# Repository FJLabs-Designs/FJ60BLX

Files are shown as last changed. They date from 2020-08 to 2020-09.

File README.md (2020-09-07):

# FJ60BLX Bluetooth 60% Mechanical Keyboard PCB

The following repository will hold the design files of the FJ60BLX Bluetooth Mechanical Keyboard PCB. This is designed to be a living repository and design files in this repository will be continually updated as the board iterates and changes.

## About this Repository

This repository contains rolling updates to the FJ60BLX Bluetooth PCB. Included are the base Eagle files (Board File, Schematic, and CAM Processor Job), the associated Gerber files for that revision, and the associated Bills of Materials. Each of these files will be segregated into their respective versions that are date-coded with the day of export. 

## Eagle Files

The core of this repository are the bare Eagle files. These files are the basis for the Gerber exports. **When using the eagle files, please remove the FJLabs and FJ60BLX branding.**

## Gerber Files

Included are the Gerber Files for manufacturing. These should be available in 5.6 format for all copper layers, and 4.5 format for all drills. Your PCB manufacturer requires these files to create the PCB itself. Additionally, included in the Gerber files are the relevant Pick and Place Coordinate/Centroid files which are needed for PCBA. 

## BOM Files

The included BOM files are available as Excel spreadsheets with LCSC links whereever possible. Certain components are not available from LCSC and must be purchased either directly from the manufacturer or from an authorized components distributor. 

## Renders

This folder includes a master list of all renders that have been sent to subscribers of the FJ60BLX mailing list and are date-coded. 

## Manufacturing Information

### Bluetooth Module

The PCB uses the MDBT40-256v3 Bluetooth module designed and manufactured by Raytac. This module must be programmed with the Adafruit Bluefruit SPI Friend firmware for compatibility with QMK. The relevant firmware has not been included as it is property of Adafruit and its respective company. However, this firmware is available for free open-source on GitHub (link not provided). Additionally, a SoftDevice file is required for programming of the bare Bluetooth module, which is included in the Adafruit repository for the Nordic 51822 chipset. 

Instructions are not included for programming the Bluetooth module over SWD, as it is more productive to purchase such modules pre-programmed directly from the manufacturer. The difference in cost between a programmed and unprogrammed module is negligble and therefore, for production, it is *highly recommended* to purchase preflashed chips.

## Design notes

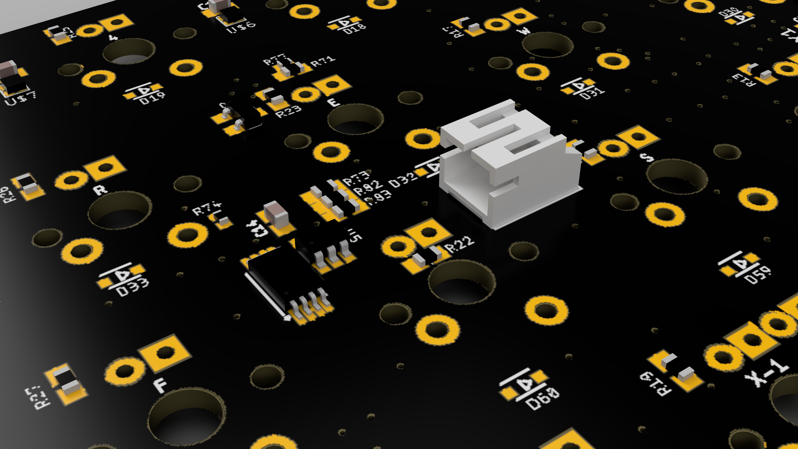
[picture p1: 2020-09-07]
Renders/v1-8-11-20-battery.png

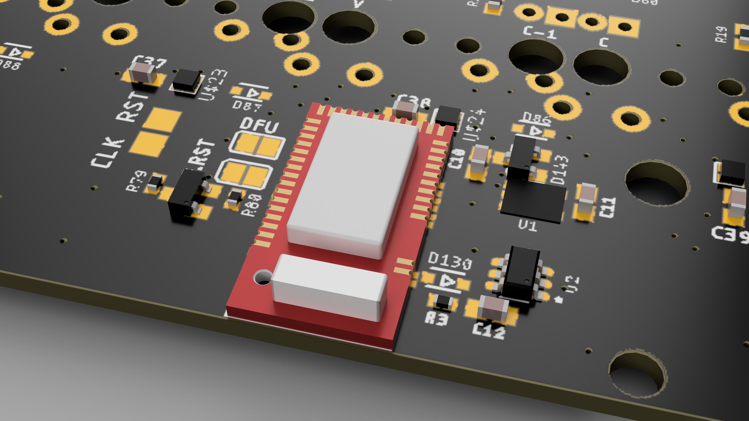
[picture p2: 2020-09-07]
Renders/v1-8-11-20-bluetooth.png

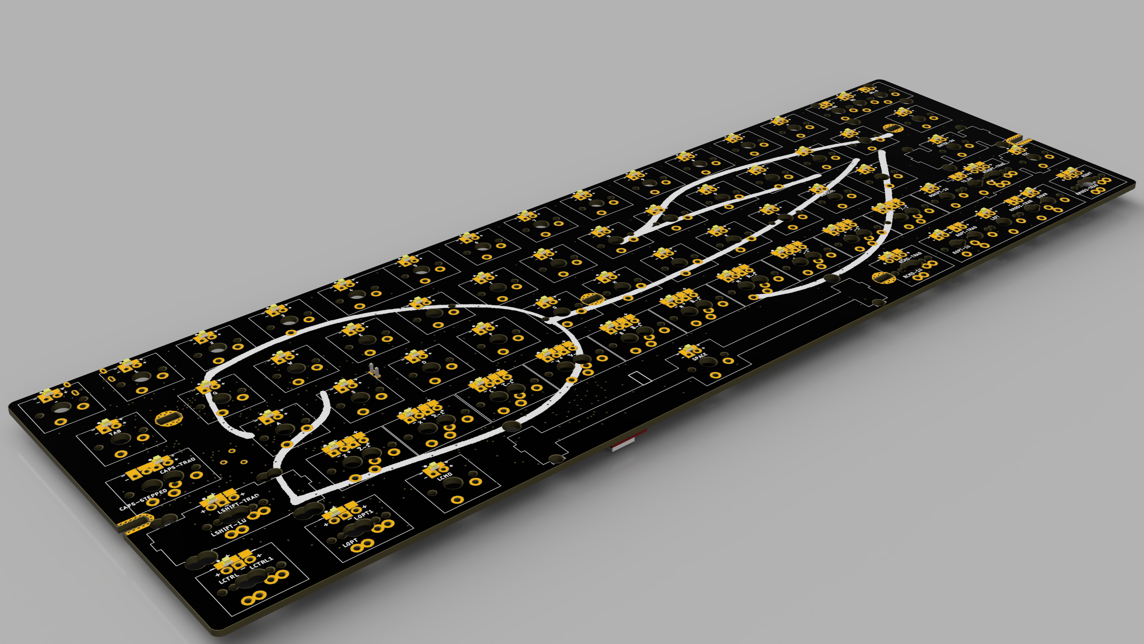
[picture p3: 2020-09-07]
Renders/v1-8-20-20-topart2.png

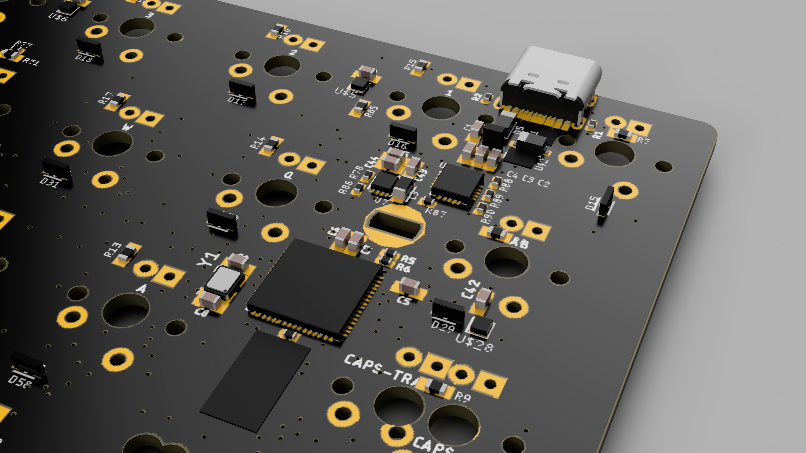
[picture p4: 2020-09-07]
Renders/v1-8-11-20-power.png

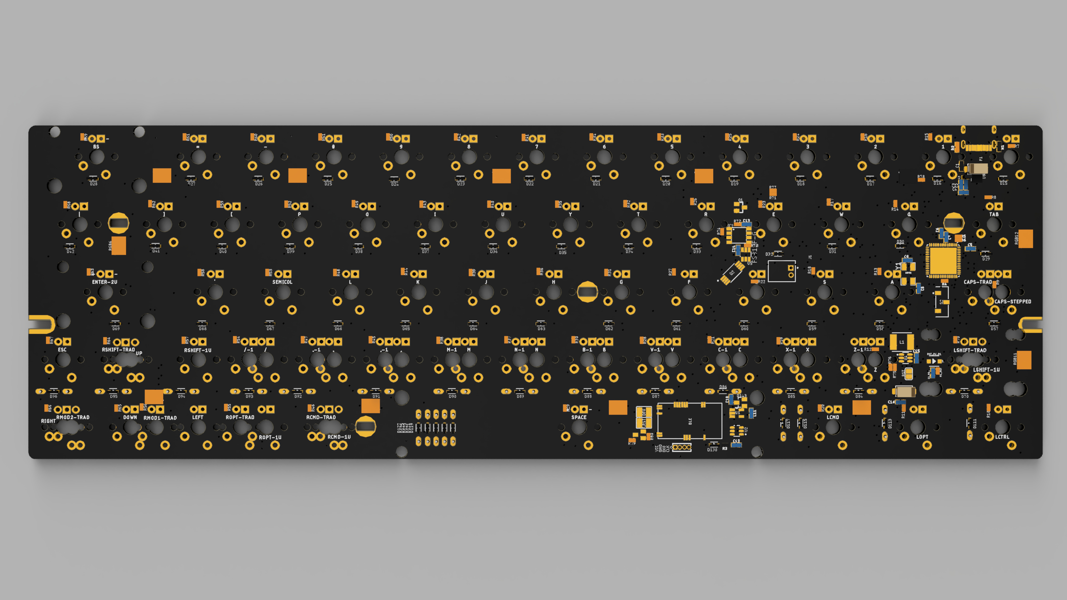
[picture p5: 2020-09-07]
Renders/v1-7-19-20-Bottom.jpg

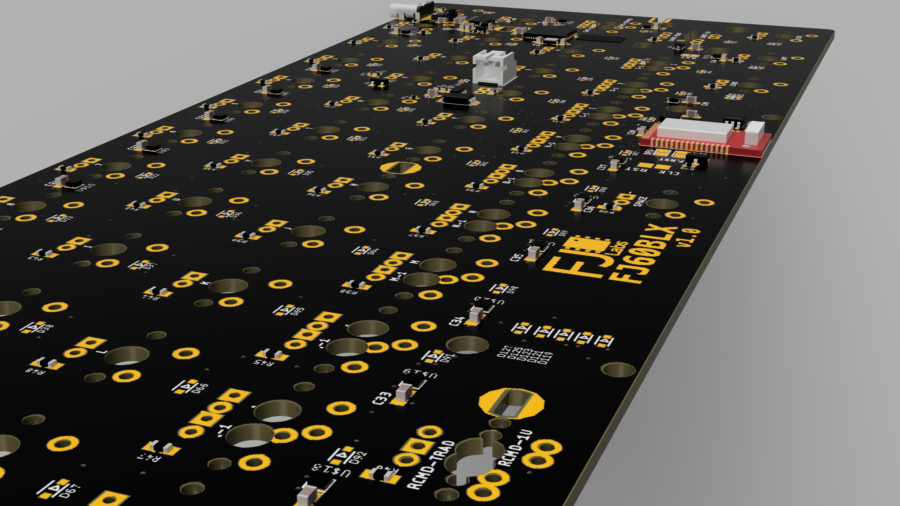
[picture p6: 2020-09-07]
Renders/v1-8-11-20-whole.png

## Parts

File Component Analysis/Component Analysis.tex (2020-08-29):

\documentclass[11pt]{article}

\usepackage[utf8]{inputenc}
\usepackage[T1]{fontenc}
\usepackage{amsmath}
\usepackage{indentfirst}
\usepackage[letterpaper]{geometry}
\usepackage{hyperref}
\usepackage{graphicx}
\usepackage{wrapfig}
\usepackage[bottom]{footmisc}
\usepackage{siunitx}
\usepackage{circuitikz}
\usepackage{array}
\usepackage{tikz}

\pagestyle{headings}

\begin{document}

\author{FJ Labs\footnotemark}
\title{FJ60BLX Component Choice and Analysis}
\date{August 21, 2020}
\maketitle

\tableofcontents

\newpage

\footnotetext{I would like to give special thanks to Hadi Iskandarani, his associated Discord group and Youtube channel, without whom this PCB design would have more errors than accuracies. As well, I would like to thank those kind enough to provide advice and support during the design stages of the board, answering my numerous questions without fail.}

\section{Introduction}

This document is intended to be a live document with a full description of the rationale for the primary component choices, the impetus behind why design choices were made, and an analysis of the availability and producibility of the components.

Major sections are divided into the core subsystems of the board starting from the core keyboard functionality then progressing to the additional functions added.

\section{Keyboard Overview}

The vision for the FJ60BLX PCB was to create an "all-in-one" PCB for the universal 60\% keyboards, including the KBDFans Tofu and 5Degrees cases, as well as similar generic cases. The primary feature draw of the keyboard is the Bluetooth functionality and full QMK support. Additional \emph{quality of life} features include under-glow RGB support and per-key backlighting. 

As such, the overarching theme of the design process has been to support Bluetooth in \emph{any way possible}. Much of the rationale behind each of the subsections follows from this core idea, and the remainder of the document should be read with it in mind.

\section{Microcontroller}

\subsection{Microcontroller Choice}

The main microcontroller for this board is the AT90USB646-MU. First and foremost, I address why this microcontroller was chosen over a smaller, cheaper, and more simple, Atmega32u4. For those knowledgable in keyboard PCB's, you will know the Atmega chip to be the bread and butter of keyboards. Unfortunately, this chip was simply not suitable for the FJ60BLX.

Let's first look at why the Atmega32U4 is so popular. First of all, it is a cheap, widely-produced microcontroller, which can easily be purchased under \$2 when produced at scale. Furthermore, it has most of the features necessary for operation under QMK, including 32KB of onboard flash memory and total of 26 I/O [input-output, GPIO] lines available. As well, it is a rather low-power device, consuming around $\SI{15}{\milli\ampere}$ at load when run with the usual specifications. It operates on a wide voltage range, functional from 2.7V to 5.5V. All these features make the chip ideal for a low-complexity device like a mechanical keyboard, whose sole purpose is to provide input and output.

\subsection{Why not the Atmega32U4?}

With that out of the way, let's talk about why I am \emph{not} using the Atmega32U4 for this keyboard, even though it seems like the perfect candidate.

The FJ60BLX consists of a matrix with rows and columns \([5,14]\). To maintain a proper matrix, as well as avoid ghosting of the keys, this, at minimum required 19 microcontroller pins. I am aware that alternative matrix combinations could have been arranged to reduce the number of pins needed (\emph{i.e.}, \([8,9]\)). However, this would not correspond logically to the actual layout of the keyboard, causing headaches when actually laying out the matrix, and even doing the keymaps in software. Thus, we are left with requiring 19 pins for the matrix.

For most boards, the Atmega32U4 can easily handle the 19 matrix pins without an issue (and that's why most boards use it). However, the FJ60BLX requires multiple additional pins, specifically for the Bluetooth support, under-glow, and backlight support. 

The Bluetooth module requires a minimum of 5 total pins (\emph{See supra., Bluetooth}). Additionally, RGB under-glow using addressable RGB LED's requires 1 pin (\emph{See supra, Under-glow}). Per-Key LED lightning using a common-cathode setup requires 1 pin (\emph{See supra, Per-Key LED)}. With this, our total pin count was brought up to 26 pins, the total available for the Atmega32U4 in terms of GPIO. Additionally, there are a few pins which are reserved for other purposes in the Atmega32U4 (\emph{i.e.}, Pin E2 (HWB)).

\subsection{Why the AT90USB646?}

As described above, the Atmega32U4 was likely not a suitable chip for this keyboard given the number of additional pins needed. Therefore, the search was on for an alternative chip. 

One of the primary drivers for the chip choice was QMK support. QMK, while being a great piece of software, has limited chip support\footnotemark \footnotetext{ \emph{See} QMK list of compatible microcontrollers at  \url{https://docs.qmk.fm/\#/compatible\_microcontrollers} }  due to its open-source nature. QMK supports two main types of microprocessors architectures, ARM and AVR. Immediately, ARM chips were ruled out, as I am not knowledgable about ARM, and do not wish to set too far out of my software comfort-zone, for a hardware project. 

Among the supported QMK AVR chips are the Atmega32U4 family, AT90USB646 family, and the Atmega32u2 family. Other AVR chips are also supported, but they do not use the LUFA USB stack, so they forgo native USB-support. Having ruled out the Atmega32U4, the Atmega32U2 family was also excluded due to even more reduced feature sets. Thus, we are left with the AT90USB646 family of chips.

The AT90USB646 family is class of chips which include the AT90USB646/647 and the AT90USB1286/1287. We'll first rule out the AT90USB1286/1287 lines. These chips contain 128KB of available flash memory (hence the product name). As QMK fits comfortable in even 32KB of flash\footnotemark \footnotetext{The Atmega32U[x] series has 32KB of flash and support QMK. Additionally, according to QMK documentation, 16KB flash chips are supportable, if features are selectively disabled from the firmware}, 128KB of flash was simply too much. We are then left with the AT90USB646/647 class.

The AT90USB646 and AT90USB647 are delineated by their USB interface version. The 646-type chips present the USB interface as a \emph{device} whereas the 647-type chips present the USB interface as a \emph{USB OTG} standard. Without diving much into the complexities of USB negotiation, the correct choice for a keyboard would be \emph{device} mode—the 646-type chips. Therefore, the final chip model was nailed down to the AT90USB646.

Of course, let's sanity check the chip to make sure it can do what we need. First of all, this chip has a total of 48 I/O lines, a much higher number compared to the 26 of the Atmega. Therefore, this chip can easily handle all the features we will throw at it. Additionally, this chip supports all the extra hardware features the Atmega32U4 does without sacrificing much. Power consumption is marginally higher, but this will be addressed in a later section.\footnotemark \footnotetext{\emph{See supra. Power Management}.}

\subsection{Package Choice}

The AT90USB646 is offered in 2 versions—a QFP and QFN package. To most, these package names seem completely foreign, but actually matter quite heavily during designing. The chips in each package are identical, but each package takes up a different amount of room of the circuit board when placed down. Therefore, care must be chosen when choosing a proper package for a chip, given constraints on board side and available room.

QFP [Quad Flat Pack] packages are very common and present themselves with exposed leads for each of the pins of the IC. \emph{See Figure 1} QFN [Quad Flat No-Leads] packages are much smaller packages, which do not have leads, but instead, have the connection points on the underside of the chip itself. \emph{See Figure 2}. 

\begin{wrapfigure}{r}{0.5\linewidth}
	\centering
	
	\caption{Atmega32U4 in QFP.}
\end{wrapfigure}

\vspace{1.5cm}

\begin{wrapfigure}{r}{0.5\linewidth}
	\centering
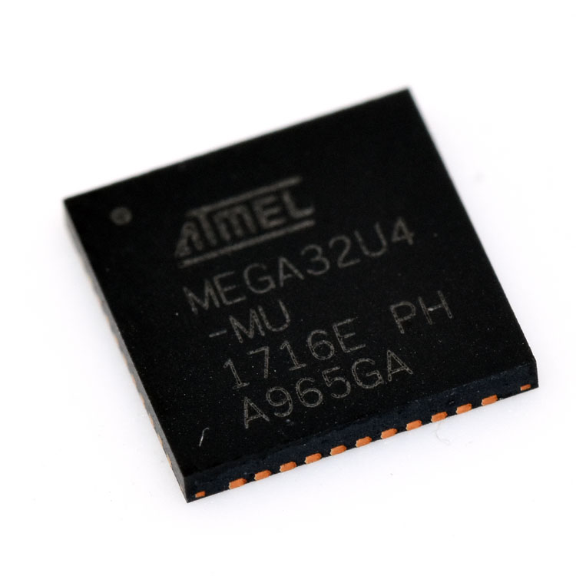
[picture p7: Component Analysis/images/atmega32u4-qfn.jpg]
	
	\caption{Atmega32U4 in QFN.}
\end{wrapfigure}	

One of the primary constraints in package choice was that I wanted the microcontroller to sit squarely in between the Tab and Q keys. Partly, this was simply for a challenge. As well, I wished to avoid having to bring the USB data lines down below to somewhere with more space like around the spacebar. As the amount of space between those two keys is actually quite small, the natural choice was to go with the QFN package.

The QFN, given its size, is not without its drawbacks. Most notably, this chip is not hand-solderable in any sense of the imagination.\footnotemark \footnotetext{I am aware that drag-soldering is possible with a QFN package. However, without enough practice and also a very skilled hand, this is an incredibly difficult task. Even most professionals would regard this task as foolish.} Another drawback is the lack of ability to detect errors in manufacturing with this package type, as the solder pads are primarily below the chip itself. These problems will hopefully be remedied through functional testing by the PCB manufacturer themselves at additional cost.

\subsection{Component Availability}

This microcontroller is a widely used part and is not expected to face any component shortages. These can be purchased from most online component distributors as well as directly from the manufacturer. As such, no production challenges are expected from this chip choice.

\section{Bluetooth}

The Bluetooth chip of choice in this build is the Raytac MDBT40-256v3,\footnotemark \footnotetext{\url{https://www.raytac.com/product/ins.php?index\_id=63}} based off the Nordic nRF51822 ARM Cortex M0. To be brief, the reason this chip was chosen was off-the-shelf QMK support\footnotemark \footnotetext{I am not a C programmer, and I do not want to redevelop a Bluetooth implementation purely from scratch.} and reasonable cost. 

\subsection{Origins of this chip}

For those versed in QMK's documentation, you will know that QMK lists a few chips as \emph{supported} with the recommended being the Adafruit Bluefruit SPI Friend.\footnotemark \footnotetext{\url{www.adafruit.com/product/2633}}. Adafruit sells this module as a "breakout board" which is a pre-built carrier module for the chip as well as any supporting components. This sounds great! However, it is over \$15. Not great.

Instead, as the breakout board is simply a carrier board, I could easily rebuild the breakout board itself on the actual PCB, adding all the supporting components and main chip myself. \emph{I would like to give a huge shoutout to Adafruit for making not only their breakout boards available to the general public, but also their associated schematics.}\footnotemark \footnotetext{\url{https://cdn-learn.adafruit.com/assets/assets/000/026/205/original/adafruit\_products\_BluefruitLESPIFriend\_sch.png?1436186237}.}. Avoiding Adafruit's breakout board brings this chip down to around \$5 at scale per-chip and a few extra dollars for the surrounding supporting components. 

\subsection{Why this specific chip?}

The chip that Adafruit used for their breakout board is the MDBT40-256v3. Alternative versions of this chip are available as well, such as the MDBT40-P256v3 and MDBT40-256RV3. Differences between models are broken down in this section.

The difference between P and non-P models is the use of a chip antenna (non-P) vs a PCB antenna (P). Notably, chip antennas have greater signal strength and increased signal-to-noise ratio compared to their PCB antenna counterparts. In my original PCB vision, most boards would go into aluminum cases such as the Tofu, which tends to obstruct radio signals from passing through.\footnotemark \footnotetext{This effect is due primarily to the Faraday effect, with the case essentially acting as a Faraday cage, blocking RF in and out. A similar issue is faced with wireless charging and metal cases.} Therefore, signal strength was of \emph{utmost} importance when choosing the Bluetooth chip. Thus, P models were removed from consideration, despite being a tiny bit cheaper.

The difference between R and non-R models is the presence of extra RAM in the R models. Non-R models present a total of 16KB of useable RAM. This was determined to be sufficient as the Adafruit breakout board uses the non-R version and the Bluetooth chips will be running the identical Adafruit firmware. Therefore, R models were removed from consideration. 

The final model of this module being produced by Raytac is the MDBT40-256v3.

\subsection{Supporting Components}

The Bluetooth module chosen needs a few major supporting components to function properly in the FJ60BLX's circuit. These include a 5V-to-3.3V regulator and a level shifter. Most of the component choice was identical to that on the Adafruit breakout board, both due to simplicity as well as reliability and component availability. No future detail is given on the associated supporting components here.

\subsection{Component Availability}

The MDBT40-256v3 will be purchased through a direct purchasing relationship with the manufacturer. These chips are not readily available through component distributors due to rather niche nature. Instead, production supply has already been established and purchasing expectations have already been provided. Furthermore, purchasing directly from the manufacturer enables them to preprogram the chip with the requisite Adafruit firmware before assembly, saving time and error.

The supporting components are widely available from most component distributors. These are not in short supply and are quite generic in their nature. They may be swapped to equivalent components as many drop-in replacements exist. As such, they are not expected to be impediments to production.

\section{Power Management}

One of the most unique elements of the FJ60BLX is the inclusion of a multi-phasic power management scheme, built around Dynamic Power Path Management.\footnotemark \footnotetext{Dynamic Power Path Management (DPPM) is a T.I. specific branding of "Power Path Management."} As such, as a litany of additional components were added to support this, detailed in this section.

\subsection{Why DPPM?}

Most keyboards do not include a DPPM solution, so why did this keyboard need it? This was due to two competing electrical "dragons" in this board: 1) power savings due to being battery powered, and 2) high power draw due to the amount of LEDs. Most boards on the market are only faced with one of these dragons they need to contend with, instead of two completely mutually-exclusive ones.\footnotemark \footnotetext{Most boards with the amount of LED's present are only available in wired modes whereas most Bluetooth boards do not have so many LED's. Even notable boards like the Anne Pro 2 have fewer LED's than this board will have fully populated.} 

These two dragons have the following effects. A computer's standard USB port is typically limited to \(500mA\) of continuous current. Therefore, this acts as the upper ceiling of power draw from the board, to allow use when connected to USB and without a battery. The high amount of LED's will draw, at full load, a total of \(450mA\).\footnotemark \footnotetext{\emph{See supra, Under-glow} and \emph{Per-Key LEDs}} Therefore, to avoid LED's unfortunately being dimmed while simultaneously charging the battery, battery charging must be limited to \(50mA\) when LEDs are at full load. A typical 1800mAh battery, however will take:

$$ \frac{1800mAh}{50mA} = 36h $$

to achieve a full charge. This number is ridiculous and completely unacceptable for day-to-day use. Alternatively, power may have been divided equally between the battery charging and LEDs, leaving a \(250mA\) for both. This would give a battery charge time of:

$$ \frac{1800mAh}{250mA} = 7.2h $$

This is a much better result and somewhat more acceptable. What would be \emph{best} would be the ability to allow the LEDs to use as much power as they want, and redirect the entire remaining power budget of 500mA to the battery charger. Essentially, if a user turns off the LED's (\emph{e.g.,} before sleeping), the battery would be able to take advantage of almost all \(500mA\) power budget, giving a charge time of:

$$ \frac{1800mAh}{500mA} = 3.6h $$

This is a much greater result and is perfect for daily usage, with charging at night. This can only be accomplished with a Dynamic Power Path Management chip.

The primary ability of DPPM is to \emph{prioritize} system load from a total power budget, and redirect all remaining power for purposes of charging the battery. 

\subsection{Battery Charger}

Knowing that DPPM was required, the search for a battery charger chip was narrowed down.\footnotemark \footnotetext{The search for the chip was limited to Microchip chips as reliability was extremely important. Furthermore, Microchip provides immaculate documentation of their chips, providing detailed descriptions and implementation diagrams. I have also personally seen these chips in other products and Adafruit breakout boards, so I am aware of their basic implementation.} The Microchip MCP73871-2AAI/L was chosen as the final battery charger chip. 

This chip is a lithium-ion battery charger with integrated load-sharing power pathing (DPPM), with a total \(1.8A\) of input current, and \(1A\) charging. This was sufficient headroom over the maximum \(500mA\) power available through USB.\footnotemark \footnotetext{Alternative USB charging specifications are categorically not supported with this board. Any charger over 5V 500mA may have the potential to damage the board irreparably.} The feature set of this chip is extremely admirable, including all the needed features, plenty of headroom, and a large amount of programmable capability.

While such a powerful chip is, of course, not entirely necessary in the context of a DPPM charger circuit, their inclusion was certainly a plus. While many of the features were disabled or left unused, the system takes advantage of a handful. The charger offers built-in overheat protection, in the event that too much current gets drawn for the thermal capacity of the board. This will help prevent runaway charging fires common in poorly designed electronics. As well, the chip offers built-in automatic input-power switching, reducing overall component count and board space. Lastly, the amount of status LED's (while not on the final board design) will make circuit troubleshooting easy in the prototyping phases.

\subsubsection{Chip Models}

The MCP73871 is a family of chips that all offer the same basic functionality. Ultimately, the MCP73871-2AAI/L was chosen for its current availability (one of the only in the family that is available).

\subsubsection{Component Availability}

This chip appears to be widely available from most electronics components distributors as well as directly from the manufacturer. As such, no production challenges are expected from this chip choice.

\subsection{System Voltage and Power Conditions}

One of the biggest challenges with a battery powered system driving LEDs is power delivery. Lithium Ion batteries are known to produce a maximum voltage of \(4.2V\) and safe minimum voltage of \(3.0V\). In a very large amount of its battery life, the battery will operate at \(3.7V\). This is of slight concern as most RGB LEDs will operate at \(3.5V < V_f < 4.3V\). In other words, the LEDs may require up to \(4.3V\) to even turn on.

Clearly, running the entire system off a battery was not feasible. Therefore, voltage must be boosted to an acceptable level before being used by the system. 

It would be trivial to boost output voltage to \(5V\), but this presents drawbacks in terms of power efficiency. The AT90USB646 can draw as little as \(7.5mA\) at \(3.3V\) and a maximum of \(20mA\) at 5V. This presents a stark battery life contrast:

$$ \frac{1800mAh}{7.5mA} = 240h < \frac{1800mAh}{20mA} = 90h $$

This is a difference between running the keyboard for over a week and only 4 days. While the LED's can not run at 3.3V, a compromise can be made, at \(4.6V\). I chose not to skirt the minimum voltage of \(4.3V\) as diodes may present a forward voltage drop of typically \(200mV\): 

\begin{equation}
\begin{aligned}
V_{in} - V_{F} = V_{usable} \\
4.6V - 0.2V = 4.4V
\end{aligned}
\end{equation}

Additionally, as the Bluetooth module runs exclusively on 3.3V, the \(4.6V\) must be regulated down.\footnotemark \footnotetext{\emph{See infra. Bluetooth}} It's incredibly important to note that linear voltage regulators have a minimum voltage drop, defined as \(V_{Dropout} = V_{in} - V_{out}\). For the linear regulator chosen as part of the Bluetooth subsystem, the accompanying datasheet defined \(\max(V_{Dropout}) = 300mV\). Therefore, 

$$ \min(V_{In}) = V_{out} + \max(V_{Dropout}) = 3.3V + 0.3V = 3.6V $$

Clearly, this is in range of the \(V_{System} = 4.6V\) discussed earlier, so this subsystem is satisfied too. Furthermore, power loss (energy wasted as heat) on the system is fairly minimal given Bluetooth Low Energy's minimal power draw of around \(15mA\).

\begin{equation}
\begin{aligned}
P &= (V_{In} - V_{Out}) \times I \\
&= (4.6V - 3.3V) \times 0.015 \\
&= 0.0195W 
\end{aligned}
\end{equation}

Lately, of note is the interaction between battery power and USB power, in the presence of a DPPM. Previously mentioned, the DPPM chip will provide power to the system through the USB port when plugged in and via the battery otherwise. Thus, you are essentially left with two possible power conditions, \(3.0V \le V_{DPPM} \le 4.2V\) and \(V_{DPPM} = 5V \pm 0.25V\). 

So far, we have only looked at situations involving battery power. Reason being, the alternative power mode actually avoids most of the considerations previously mentioned. With \(V_{System} = 5V\), all LED's are easily driven. Furthermore, since the board is plugged in, battery life is not a concern. Lastly, the power loss of the Bluetooth chip is still quite minimal at \(0.0255W\). 

\subsection{Boost Converter}

Having decided on an appropriate system voltage, the final step was actually creating the voltage. It's important to note that battery voltage will always be lower than the system voltage, in other words, \(\forall V_{Batt}, V_{Batt} < V_{System}\). Therefore, in order to bring \(V_{Batt}\) to \(V_{System}\), we rely on a boost converter. The boost converter chosen was the TPS61252DSGT.

\subsubsection{Synchronous and Asynchronous Boost Converters}

There are two main types of boost converters available, synchronous and asynchronous. The basic method of operation of both is very similar, using energy stored in a magnetic field to provide additional voltage, with output voltage being controlled by a switching MOSFET that injects extra energy at the right time. The difference between the two boost "topologies" lies in the use of either a Schottky diode or a second MOSFET to control flyback current. 

As previously mentioned, all diodes have a forward voltage drop, \(V_F\). MOSFETs on the other hand behave similarly to "ideal diodes," theoretical one-way electric controls with a \(V_f \approx 0\). Asynchronous boost converters use a diode while a synchronous one uses a MOSFET. Recall how we also calculated power loss, which we can do similarly for an asynchronous converter, assuming an arbitrary \(V_{In}\) of a diode with a \(V_F = 300mV\), typical of Schottky diodes, and a current of \(500mA\).

\begin{equation}
\begin{aligned}
	P_{loss} &= (V_{In} - V_{Out}) \times I \\
	&= (V_{In} - (V_{In} - V_F) \times I \\
	&= V_F \times I \\
	&= 0.3V \times 0.5A \\
	P_{loss} &= 0.15W
\end{aligned}	
\end{equation}

While this may not seem like much, bear in mind that system at \(5V\) and \(500mA\) only consumes a power of \(2.5W\). This presents a 6\% power loss, a very inefficient design. A synchronous boost converter would have a power loss instead approaching zero, which is ideal. 

Therefore, in order to improve efficiency (and extend battery life), boost converter choices were limited to synchronous boost converters.

\subsubsection{Inductors and Switching Frequency}

As just mentioned, boost converters operate by storing energy in a magnetic field and later releasing this energy back into the circuit.\footnotemark \footnotetext{This arises out of Faraday's law of induction and Lenz's law.} The magnetic field is generated typically by an inductor. These are frequently seen as large windings of copper wire around a center core. While storing energy in the coil is great, if it is only stored and released once, that's not a useful change in voltage—that is merely a voltage spike, not at all helpful at driving components.

Instead, boost converters operate by storing and releasing energy from the magnetic field many hundreds of thousands of times a second. This gives boost converters the name "switch-mode power supply," effectively switching the coil on and off extremely frequently. If done fast enough, this produces close to a steady voltage at a higher level than input. 

The inductance (or amount of stored energy) is related closely to the switching frequency of the boost converter. If a switching frequency is lower, an inductor must store more energy (have a higher inductance) to bring the voltage back up to the target voltage. Conversely, a higher switching frequency requires a lower overall inductance. Higher inductance can be achieved through either a larger inductor or more coil windings.

As the board is fairly space constrained,\footnotemark \footnotetext{All power components were placed between the USB port and the Tab/Q keys. There was very little amount of room to work with.}, the inductor had to be quite small. Therefore, switching frequency had to be quite high to achieve the desired output voltage. Therefore, this limited boost converter choices to those operating above 1MHz.

\subsubsection{Part Choice}

Part consideration was narrowed down to Texas Instruments chips. This is due to previous experience using Texas Instruments boost converters for other projects. Additionally, since this component is extraordinarily critical to the rest of the board, reliability was vital and T.I. has a strong reputation in that regard. 

The final choice of the TPS61252 was due to its very high switching frequency of 3.25MHz, voltage adjustability, and high current rating. This chip also provides a unique mode known as "100\% Duty Cycle Mode." This mode activates if \(V_{in} > V_{System}\) (\emph{i.e.}, when connected to USB), allowing all power to bypass the boost converter entirely, achieving almost 100\% efficiency with near zero power loss. 

\subsubsection{Resulting Output Voltage}

The TPS61252 has a programmable output voltage, which operates on a feedback loop. According to the accompanying data sheet, the feedback loop is created through a resistor voltage divider, with the output voltage set by the following equation:

$$ V_{Out} = V_{FB} \times \left( 1 + \frac{R_1}{R_2} \right) $$

The data sheet further gives \(V_{FB} = 1.2V \) and we assume that \(R_2 = \SI{100}{\kilo\ohm}\)\footnotemark \footnotetext{This value is assumed as \(\SI{100}{\kilo\ohm}\) is used elsewhere on the board. \emph{See supra. Passives}.} Keeping our desired \(V_{Out} = 4.6V\) gives us:

\begin{equation}
\begin{aligned}
	4.6V &= 1.2V \times \left( 1 + \frac{R_1}{100000} \right) \\
	R_1 &= \SI{283.3}{\kilo\ohm}
\end{aligned}	
\end{equation}

Unfortunately, \SI{283.3}{\kilo\ohm} is not a readily available resistor value. Therefore, the closest resistor value was chosen, which came out to be \SI{270}{\kilo\ohm}. This gives a resulting \(V_{Out}\) of:

\begin{equation}
\begin{aligned}
	V_{Out} &= 1.2V \times \left( 1 + \frac{270000}{100000} \right) \\
	&= 4.44V
\end{aligned}	
\end{equation}

While this value is lower than our originally desired value of \(4.6V\), this is still within range for all functionality of the board and completely acceptable, using the calculations we ran through earlier in this section.

\subsubsection{Inductor Choice}

Inductor choice with this chip was very satisfying, requiring only a $\SI{1}{\micro\henry}$ inductor according to the data sheet. $\SI{1}{\micro\henry}$ inductors are extremely widely available in tiny package sizes, perfect for the space constrained board. 

However, inductance is not the only requirement to consider—amperage must also be taken into account. According to the accompanying data sheet, maximum current passing through the inductor may be calculated with the following set of equations:

\begin{equation}
\begin{aligned}
	I_L &= I_{Sys} + \frac{V_{In} \times D}{L \times f} \\
	D &= 1 - \frac{V_{in} \times \eta}{V_{Out}} \\
\end{aligned}
\end{equation}

$\eta$ is defined to be the estimated efficiency of the boost converter across all ranges, with the data sheet providing $\eta = 0.9$. Therefore, we can calculate $D$ as:

$$ D = 1 - \frac{3V * 0.9}{4.44V} = 0.3919 $$

We can then use this to get estimated inductor current required:

\begin{equation}
\begin{aligned}
	I_L &= 0.5A + \frac{3.0V \times 0.3919}{0.000001 \times 3250000} \\
	&= 0.862A
\end{aligned}	
\end{equation}

With this result, some additional buffer room was added, and the final inductor was selected to handle 1.5A. 

\subsection{Component Availability}

The TPS61252 appears to be widely available from most electronics components distributors as well as directly from the manufacturer. As such, no production challenges are expected from this chip choice.

\section{Under-glow LED's}
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

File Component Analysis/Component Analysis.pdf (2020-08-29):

## FJ60BLX Component Choice and Analysis

FJ Labs∗
August 21, 2020

### Contents

1 Introduction | 2
2 Keyboard Overview | 2
3 Microcontroller | 2
4 Bluetooth | 5
5 Power Management | 7

1

CONTENTS | 2
6 Under-glow LED’s | 13
7 Per-Key LED’s | 18
8 Passives | 22
9 Miscellaneous Components | 27

1 INTRODUCTION | 3

### 1 Introduction

This document is intended to be a live document with a full description of the rationale for the primary component choices, the impetus behind why design choices were made, and an analysis of the availability and producibility of the components.
Major sections are divided into the core subsystems of the board starting from the core keyboard functionality then progressing to the additional functions added.

### 2 Keyboard Overview

The vision for the FJ60BLX PCB was to create an "all-in-one" PCB for the universal 60% keyboards, including the KBDFans Tofu and 5Degrees cases, as well as similar generic cases. The primary feature draw of the keyboard is the Bluetooth functionality and full QMK support. Additional quality of life features include under-glow RGB support and per-key backlighting.
As such, the overarching theme of the design process has been to support Bluetooth in any way possible. Much of the rationale behind each of the subsections follows from this core idea, and the remainder of the document should be read with it in mind.

### 3 Microcontroller

### 3.1 Microcontroller Choice

The main microcontroller for this board is the AT90USB646-MU. First and foremost, I address why this microcontroller was chosen over a smaller, cheaper, and more simple, Atmega32u4. For those knowledgable in keyboard PCB’s, you will know the Atmega chip to be the bread and butter of keyboards. Unfortunately, this chip was simply not suitable for the FJ60BLX.
Let’s first look at why the Atmega32U4 is so popular. First of all, it is a cheap, widelyproduced microcontroller, which can easily be purchased under $2 when produced at scale. Furthermore, it has most of the features necessary for operation under QMK, including 32KB of onboard flash memory and total of 26 I/O [input-output, GPIO] lines available. As well, it is a rather low-power device, consuming around 15 mA at load when run with the usual specifications. It operates on a wide voltage range, functional from 2.7V to 5.5V. All these features make the chip ideal for a low-complexity device like a mechanical keyboard, whose sole purpose is to provide input and output.

0I would like to give special thanks to Hadi Iskandarani, his associated Discord group and Youtube channel, without whom this PCB design would have more errors than accuracies. As well, I would like to thank those kind enough to provide advice and support during the design stages of the board, answering my numerous questions without fail.

3 MICROCONTROLLER | 4

### 3.2 Why not the Atmega32U4?

With that out of the way, let’s talk about why I am not using the Atmega32U4 for this keyboard, even though it seems like the perfect candidate.
The FJ60BLX consists of a matrix with rows and columns [5, 14]. To maintain a proper matrix, as well as avoid ghosting of the keys, this, at minimum required 19 microcontroller pins. I am aware that alternative matrix combinations could have been arranged to reduce the number of pins needed (i.e., [8, 9]). However, this would not correspond logically to the actual layout of the keyboard, causing headaches when actually laying out the matrix, and even doing the keymaps in software. Thus, we are left with requiring 19 pins for the matrix.
For most boards, the Atmega32U4 can easily handle the 19 matrix pins without an issue (and that’s why most boards use it). However, the FJ60BLX requires multiple additional pins, specifically for the Bluetooth support, under-glow, and backlight support.
The Bluetooth module requires a minimum of 5 total pins (See supra., Bluetooth). Additionally, RGB under-glow using addressable RGB LED’s requires 1 pin (See supra, Under-glow). Per-Key LED lightning using a common-cathode setup requires 1 pin (See supra, Per-Key LED). With this, our total pin count was brought up to 26 pins, the total available for the Atmega32U4 in terms of GPIO. Additionally, there are a few pins which are reserved for other purposes in the Atmega32U4 (i.e., Pin E2 (HWB)).

### 3.3 Why the AT90USB646?

As described above, the Atmega32U4 was likely not a suitable chip for this keyboard given the number of additional pins needed. Therefore, the search was on for an alternative chip.
One of the primary drivers for the chip choice was QMK support. QMK, while being a great piece of software, has limited chip support¹ due to its open-source nature. QMK supports two main types of microprocessors architectures, ARM and AVR. Immediately, ARM chips were ruled out, as I am not knowledgable about ARM, and do not wish to set too far out of my software comfort-zone, for a hardware project.
Among the supported QMK AVR chips are the Atmega32U4 family, AT90USB646 family, and the Atmega32u2 family. Other AVR chips are also supported, but they do not use the LUFA USB stack, so they forgo native USB-support. Having ruled out the Atmega32U4, the Atmega32U2 family was also excluded due to even more reduced feature sets. Thus, we are left with the AT90USB646 family of chips.
The AT90USB646 family is class of chips which include the AT90USB646/647 and the AT90USB1286/1287. We’ll first rule out the AT90USB1286/1287 lines. These chips contain 128KB of available flash memory (hence the product name). As QMK fits comfortable in

1See QMK list of compatible microcontrollers at (https://docs.qmk.fm/#/compatible_microcontrollers) https://docs.qmk.fm/#/compatible_microcontrollers

3 MICROCONTROLLER | 5

even 32KB of flash², 128KB of flash was simply too much. We are then left with the AT90USB646/647 class.
The AT90USB646 and AT90USB647 are delineated by their USB interface version. The 646-type chips present the USB interface as a device whereas the 647-type chips present the USB interface as a USB OTG standard. Without diving much into the complexities of USB negotiation, the correct choice for a keyboard would be device mode—the 646-type chips. Therefore, the final chip model was nailed down to the AT90USB646.
Of course, let’s sanity check the chip to make sure it can do what we need. First of all, this chip has a total of 48 I/O lines, a much higher number compared to the 26 of the Atmega. Therefore, this chip can easily handle all the features we will throw at it. Additionally, this chip supports all the extra hardware features the Atmega32U4 does without sacrificing much. Power consumption is marginally higher, but this will be addressed in a later section.

3

### 3.4 Package Choice

The AT90USB646 is offered in 2 versions—a QFP and QFN package. To most, these package names seem completely foreign, but actually matter quite heavily during designing. The chips in each package are identical, but each package takes up a different amount of room of the circuit board when placed down. Therefore, care must be chosen when choosing a proper package for a chip, given constraints on board side and available room.
QFP [Quad Flat Pack] packages are very common and present themselves with exposed leads for each of the pins of the IC. See Figure 1 QFN [Quad Flat No-Leads] packages are much smaller packages, which do not have leads, but instead, have the connection points on the underside of the chip itself. See Figure 2.

Figure 1: Atmega32U4 in QFP.

2The Atmega32U[x] series has 32KB of flash and support QMK. Additionally, according to QMK documentation, 16KB flash chips are supportable, if features are selectively disabled from the firmware 3See supra. Power Management.

4 BLUETOOTH | 6

Figure 2: Atmega32U4 in QFN.

One of the primary constraints in package choice was that I wanted the microcontroller to sit squarely in between the Tab and Q keys. Partly, this was simply for a challenge. As well, I wished to avoid having to bring the USB data lines down below to somewhere with more space like around the spacebar. As the amount of space between those two keys is actually quite small,
the natural choice was to go with the QFN
package.
The QFN, given its size, is not without its drawbacks. Most notably, this chip is not hand-solderable in any sense of the imagination.

4 Another drawback is the lack of ability to detect errors in manufacturing with this package type, as the solder pads are primarily below the chip itself. These problems will hopefully be remedied through functional testing by the PCB manufacturer themselves at additional cost.

### 3.5 Component Availability

This microcontroller is a widely used part and is not expected to face any component shortages. These can be purchased from most online component distributors as well as directly from the manufacturer. As such, no production challenges are expected from this chip choice.

### 4 Bluetooth

The Bluetooth chip of choice in this build is the Raytac MDBT40-256v3,

5 based off
the Nordic nRF51822 ARM Cortex M0. To be brief, the reason this chip was chosen was off-the-shelf QMK support⁶ and reasonable cost.

### 4.1 Origins of this chip

For those versed in QMK’s documentation, you will know that QMK lists a few chips as supported with the recommended being the Adafruit Bluefruit SPI Friend.

7. Adafruit

4I am aware that drag-soldering is possible with a QFN package. However, without enough practice and also a very skilled hand, this is an incredibly difficult task. Even most professionals would regard this task as foolish. 5https://www.raytac.com/product/ins.php?index_id=63 6I am not a C programmer, and I do not want to redevelop a Bluetooth implementation purely from

scratch. 7www.adafruit.com/product/2633

4 BLUETOOTH | 7

sells this module as a "breakout board" which is a pre-built carrier module for the chip as well as any supporting components. This sounds great! However, it is over $15. Not great. Instead, as the breakout board is simply a carrier board, I could easily rebuild the breakout board itself on the actual PCB, adding all the supporting components and main chip myself. I would like to give a huge shoutout to Adafruit for making not only their breakout boards available to the general public, but also their associated schematics.

8. Avoiding
Adafruit’s breakout board brings this chip down to around $5 at scale per-chip and a few extra dollars for the surrounding supporting components.

### 4.2 Why this specific chip?

The chip that Adafruit used for their breakout board is the MDBT40-256v3. Alternative versions of this chip are available as well, such as the MDBT40-P256v3 and MDBT40-256RV3. Differences between models are broken down in this section.
The difference between P and non-P models is the use of a chip antenna (non-P) vs a PCB antenna (P). Notably, chip antennas have greater signal strength and increased signalto-noise ratio compared to their PCB antenna counterparts. In my original PCB vision, most boards would go into aluminum cases such as the Tofu, which tends to obstruct radio
signals from passing through. | 9 Therefore, signal strength was of utmost importance when
choosing the Bluetooth chip. Thus, P models were removed from consideration, despite being a tiny bit cheaper.
The difference between R and non-R models is the presence of extra RAM in the R models. Non-R models present a total of 16KB of useable RAM. This was determined to be sufficient as the Adafruit breakout board uses the non-R version and the Bluetooth chips will be running the identical Adafruit firmware. Therefore, R models were removed from consideration.
The final model of this module being produced by Raytac is the MDBT40-256v3.

### 4.3 Supporting Components

The Bluetooth module chosen needs a few major supporting components to function properly in the FJ60BLX’s circuit. These include a 5V-to-3.3V regulator and a level shifter. Most of the component choice was identical to that on the Adafruit breakout board, both due to simplicity as well as reliability and component availability. No future detail is given on the associated supporting components here.

8https://cdn-learn.adafruit.com/assets/assets/000/026/205/original/adafruit_products_BluefruitLESPIFriend_sch.png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. 9This effect is due primarily to the Faraday effect, with the case essentially acting as a Faraday cage,

blocking RF in and out. A similar issue is faced with wireless charging and metal cases.

5 POWER MANAGEMENT | 8

### 4.4 Component Availability

The MDBT40-256v3 will be purchased through a direct purchasing relationship with the manufacturer. These chips are not readily available through component distributors due to rather niche nature. Instead, production supply has already been established and purchasing expectations have already been provided. Furthermore, purchasing directly from the manufacturer enables them to preprogram the chip with the requisite Adafruit firmware before assembly, saving time and error.
The supporting components are widely available from most component distributors. These are not in short supply and are quite generic in their nature. They may be swapped to equivalent components as many drop-in replacements exist. As such, they are not expected to be impediments to production.

### 5 Power Management

One of the most unique elements of the FJ60BLX is the inclusion of a multi-phasic
power management scheme, built around Dynamic Power Path Management. | 10 As such,
as a litany of additional components were added to support this, detailed in this section.

### 5.1 Why DPPM?

Most keyboards do not include a DPPM solution, so why did this keyboard need it? This was due to two competing electrical "dragons" in this board: 1) power savings due to being battery powered, and 2) high power draw due to the amount of LEDs. Most boards on the market are only faced with one of these dragons they need to contend with, instead of two completely mutually-exclusive ones.

11
These two dragons have the following effects. A computer’s standard USB port is typically limited to 500mA of continuous current. Therefore, this acts as the upper ceiling of power draw from the board, to allow use when connected to USB and without a battery. The
high amount of LED’s will draw, at full load, a total of 450mA. | 12 Therefore, to avoid LED’s
unfortunately being dimmed while simultaneously charging the battery, battery charging must be limited to 50mA when LEDs are at full load. A typical 1800mAh battery, however will take:

1800mAh
50mA = 36h

10Dynamic Power Path Management (DPPM) is a T.I. specific branding of "Power Path Management." 11Most boards with the amount of LED’s present are only available in wired modes whereas most

Bluetooth boards do not have so many LED’s. Even notable boards like the Anne Pro 2 have fewer LED’s than this board will have fully populated. 12See supra, Under-glow and Per-Key LEDs

5 POWER MANAGEMENT | 9

to achieve a full charge. This number is ridiculous and completely unacceptable for day-to-day use. Alternatively, power may have been divided equally between the battery charging and LEDs, leaving a 250mA for both. This would give a battery charge time of:

1800mAh
250mA = 7.2h
This is a much better result and somewhat more acceptable. What would be best would be the ability to allow the LEDs to use as much power as they want, and redirect the entire remaining power budget of 500mA to the battery charger. Essentially, if a user turns off the LED’s (e.g., before sleeping), the battery would be able to take advantage of almost all 500mA power budget, giving a charge time of:

1800mAh
500mA = 3.6h
This is a much greater result and is perfect for daily usage, with charging at night. This can only be accomplished with a Dynamic Power Path Management chip.
The primary ability of DPPM is to prioritize system load from a total power budget, and redirect all remaining power for purposes of charging the battery.

### 5.2 Battery Charger

Knowing that DPPM was required, the search for a battery charger chip was narrowed down.

13 The Microchip MCP73871-2AAI/L was chosen as the final battery charger chip. This chip is a lithium-ion battery charger with integrated load-sharing power pathing (DPPM), with a total 1.8A of input current, and 1A charging. This was sufficient headroom
over the maximum 500mA power available through USB. | 14 The feature set of this chip is
extremely admirable, including all the needed features, plenty of headroom, and a large amount of programmable capability.
While such a powerful chip is, of course, not entirely necessary in the context of a DPPM charger circuit, their inclusion was certainly a plus. While many of the features were disabled or left unused, the system takes advantage of a handful. The charger offers built-in overheat protection, in the event that too much current gets drawn for the thermal capacity of the board. This will help prevent runaway charging fires common in poorly designed electronics. As well, the chip offers built-in automatic input-power switching, reducing overall component count and board space. Lastly, the amount of status LED’s (while not on the final board design) will make circuit troubleshooting easy in the prototyping phases.

13The search for the chip was limited to Microchip chips as reliability was extremely important. Furthermore, Microchip provides immaculate documentation of their chips, providing detailed descriptions and implementation diagrams. I have also personally seen these chips in other products and Adafruit breakout boards, so I am aware of their basic implementation. 14Alternative USB charging specifications are categorically not supported with this board. Any charger

over 5V 500mA may have the potential to damage the board irreparably.

5 POWER MANAGEMENT | 10

### 5.2.1 Chip Models

The MCP73871 is a family of chips that all offer the same basic functionality. Ultimately, the MCP73871-2AAI/L was chosen for its current availability (one of the only in the family that is available).
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

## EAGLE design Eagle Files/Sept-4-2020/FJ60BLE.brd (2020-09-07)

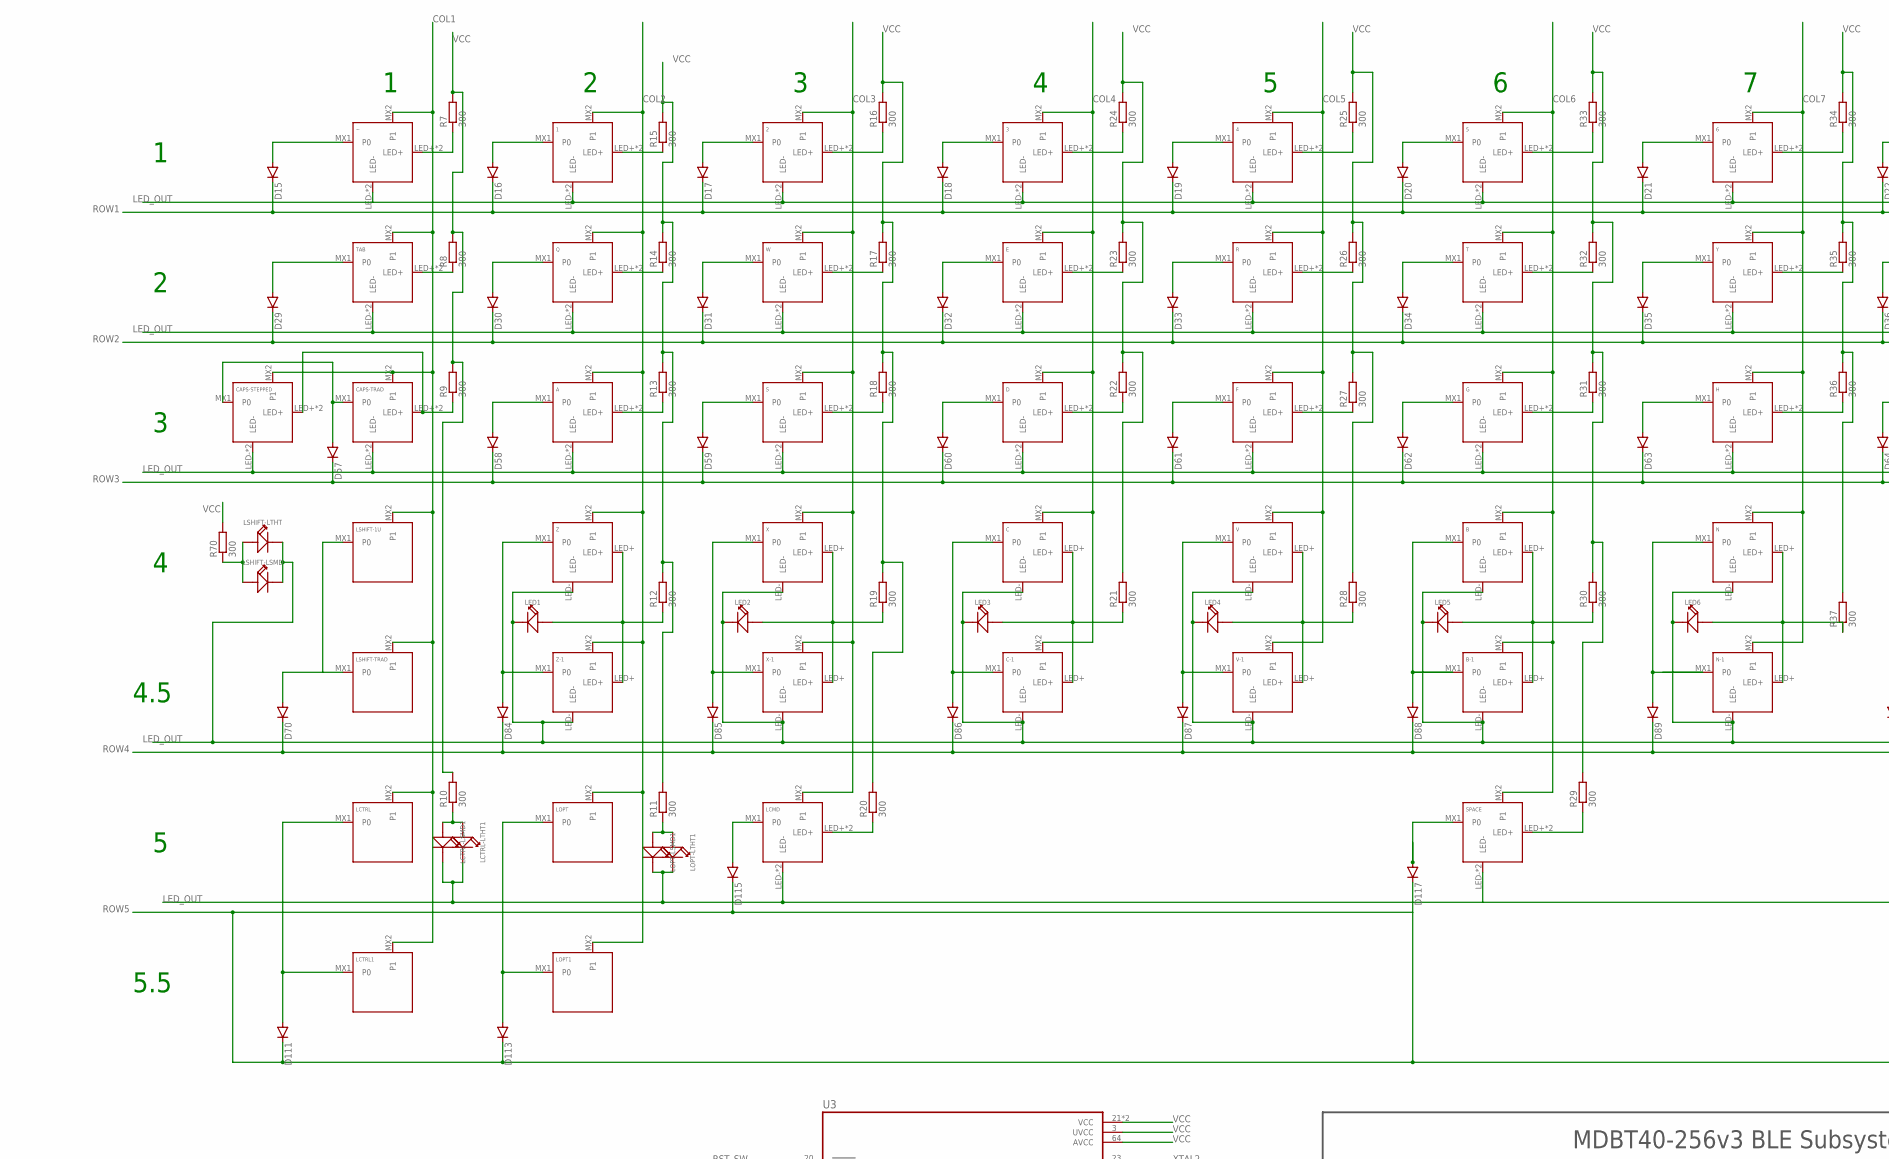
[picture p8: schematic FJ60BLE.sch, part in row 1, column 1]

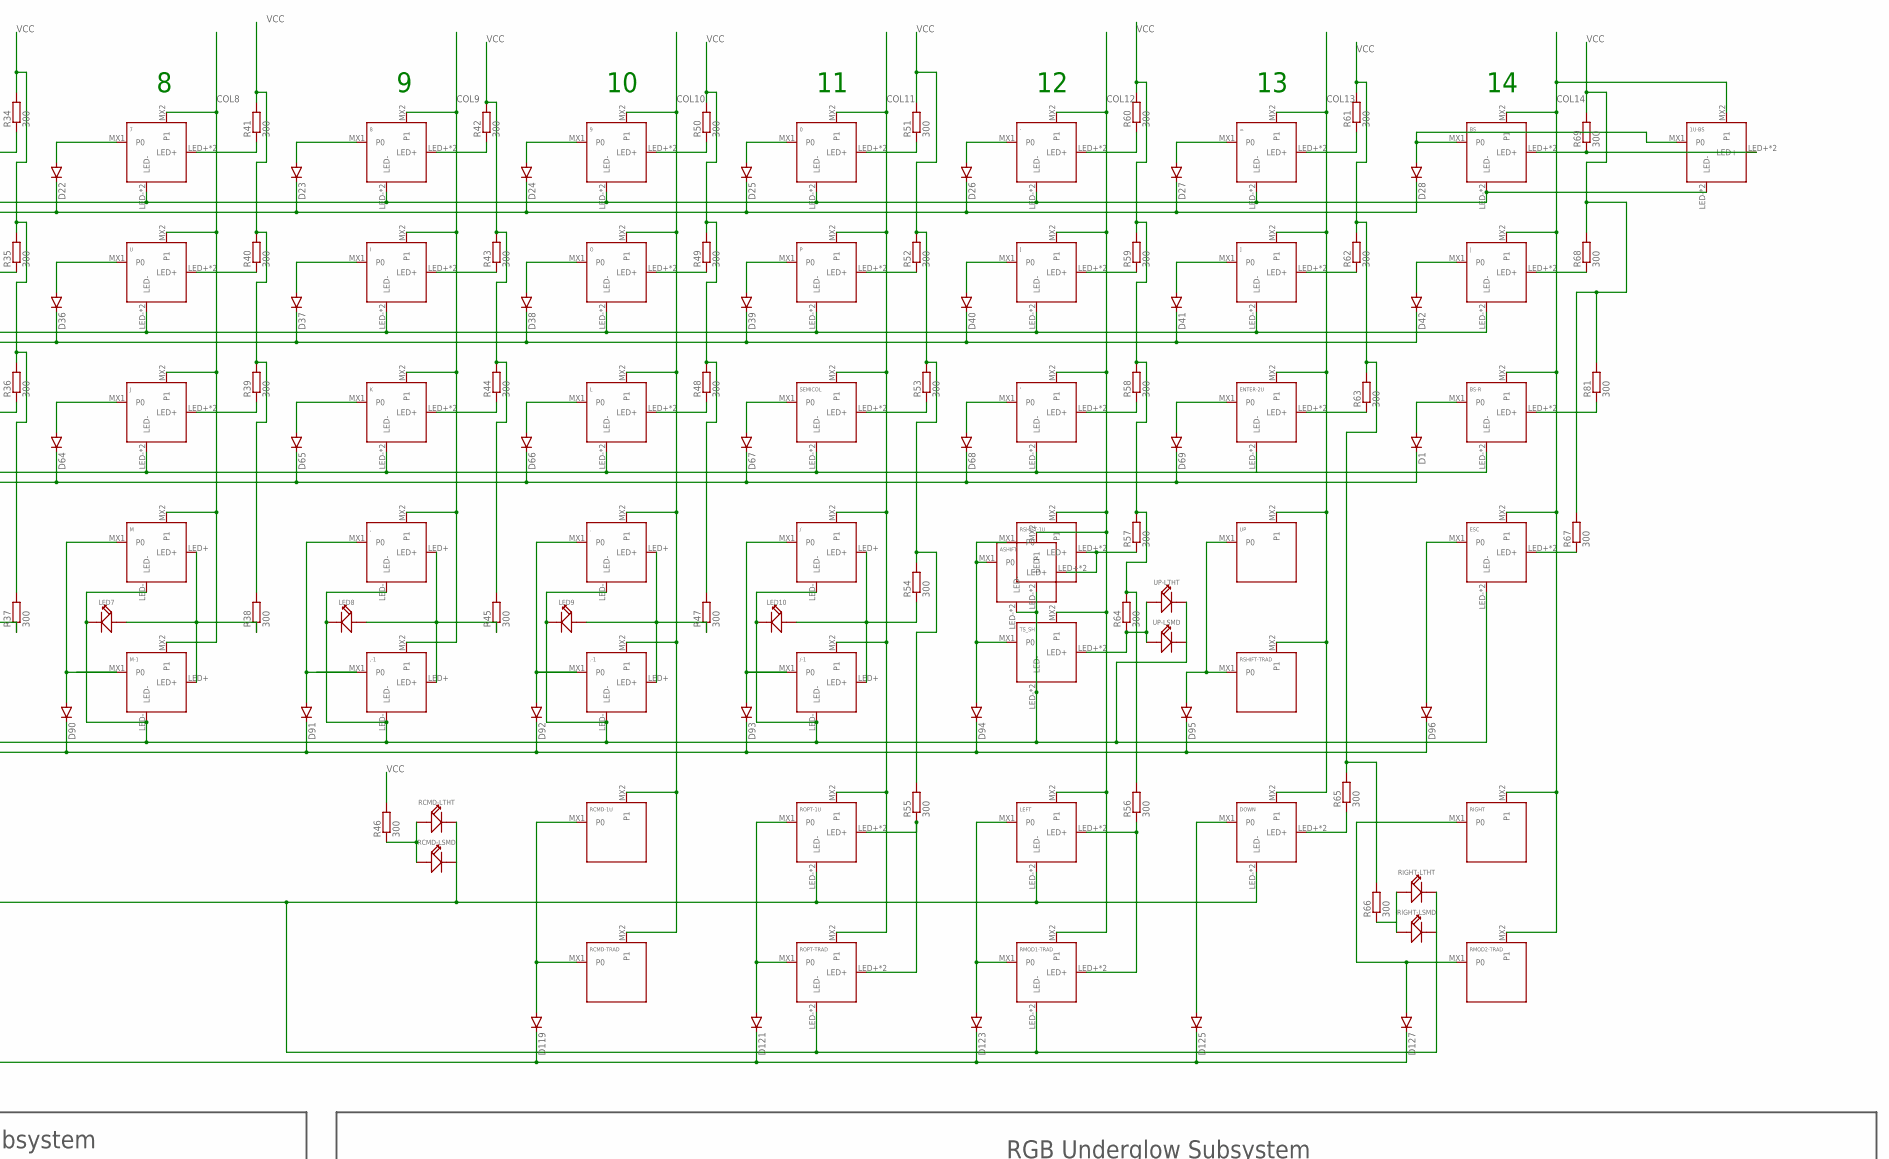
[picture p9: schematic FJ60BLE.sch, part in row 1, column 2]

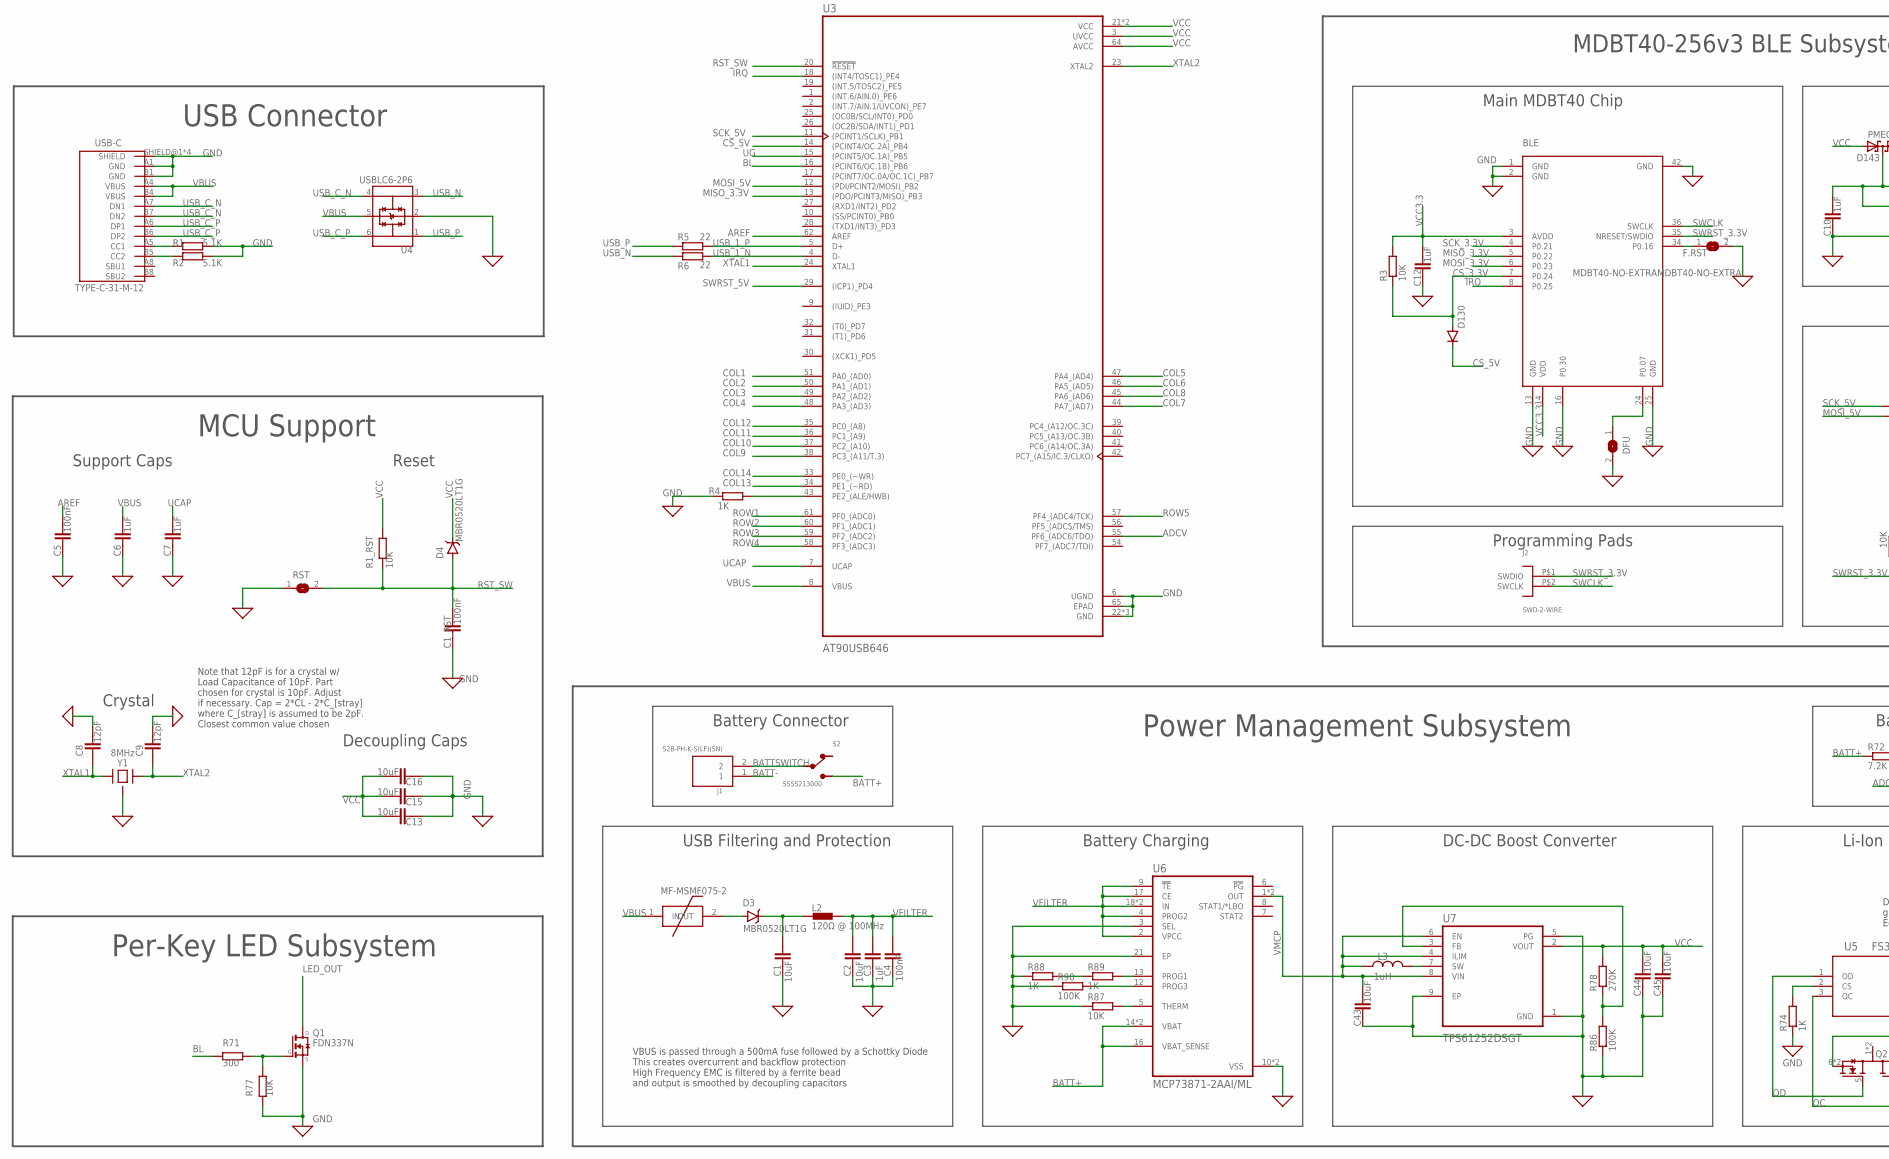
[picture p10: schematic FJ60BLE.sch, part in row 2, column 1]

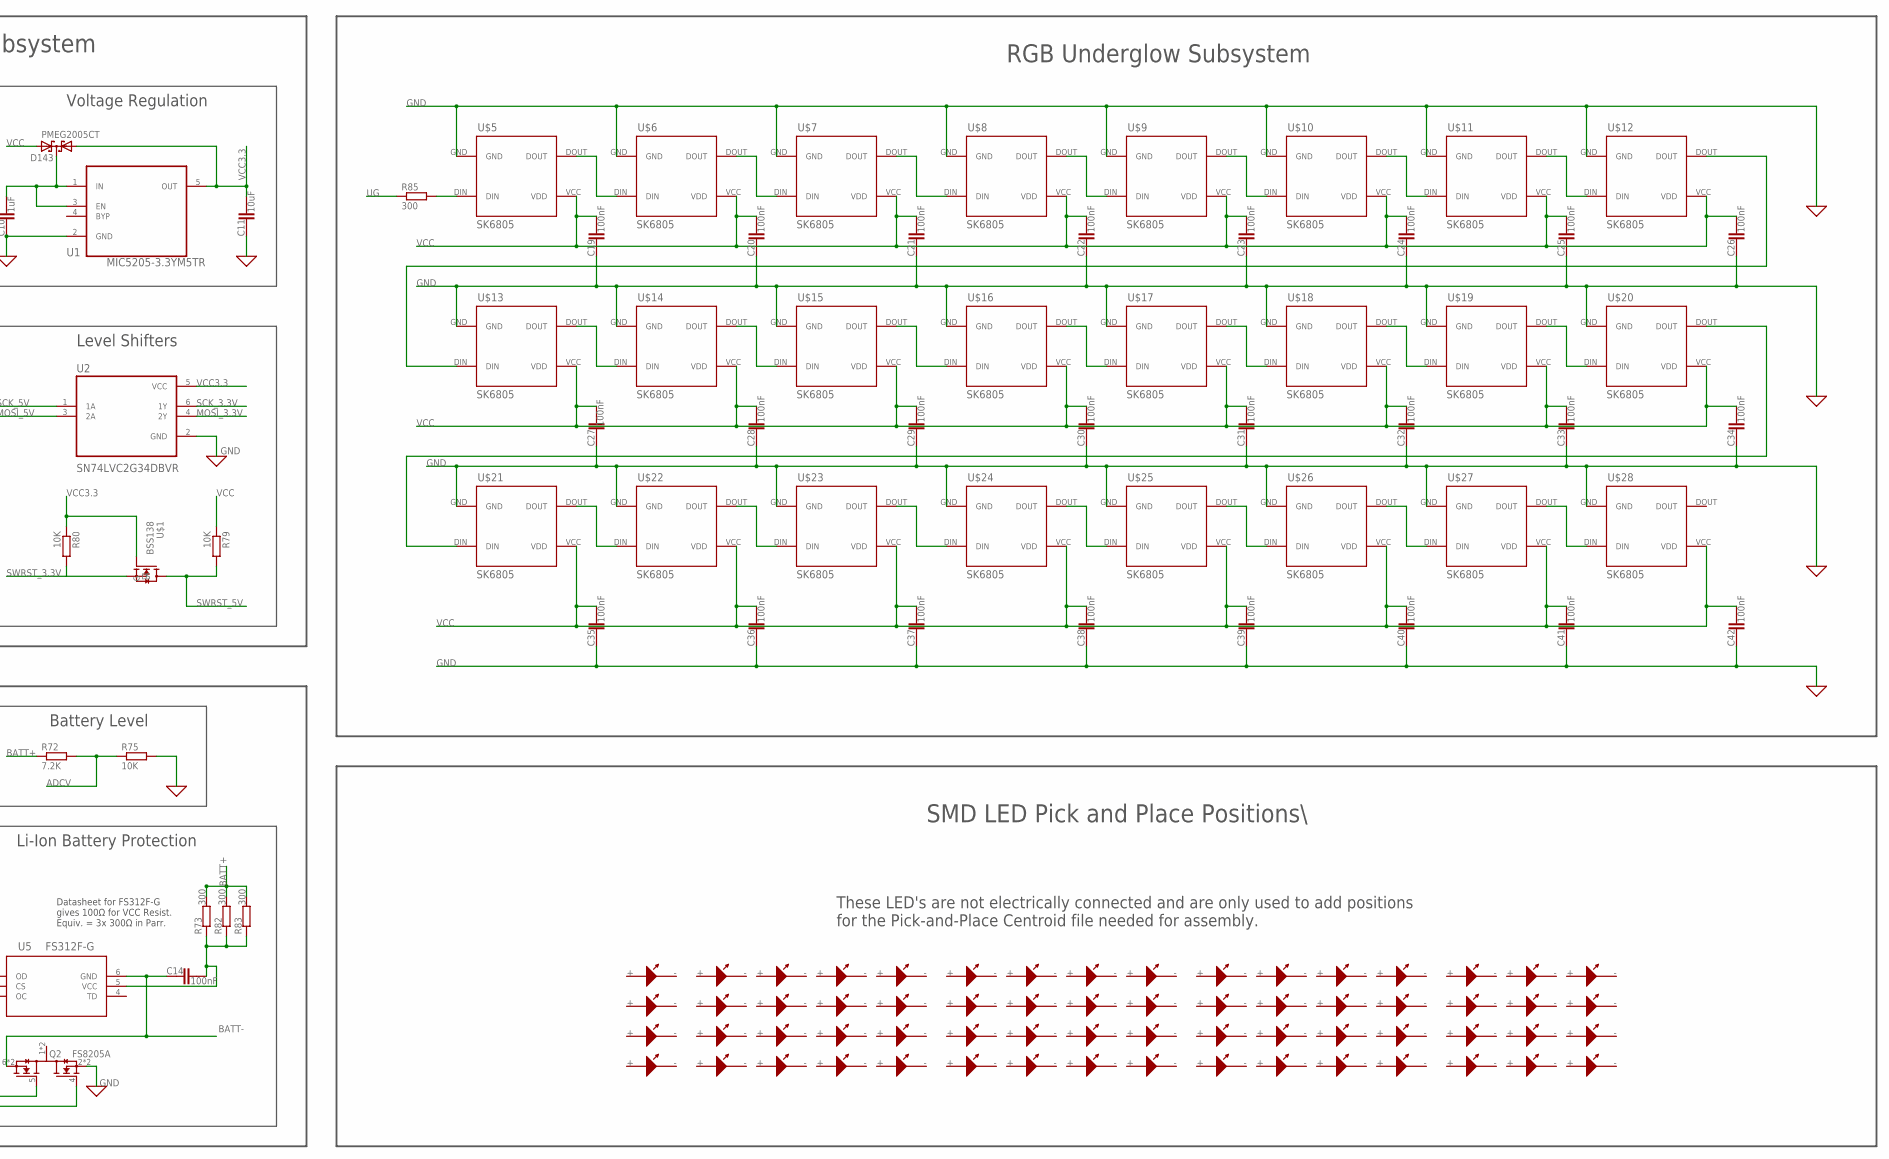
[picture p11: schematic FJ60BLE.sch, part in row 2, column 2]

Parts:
0, 1, 1U-BS, 2, 3, 4, 5, 6, 7, 8, 9: KEYSWITCH-THTSMDLED-MX-1U-THTSMDLED; MX-1U-THTSMDLED
': KEYSWITCH-THTSMDLED-MX-1U-THTSMDLED; MX-1U-THTSMDLED
,: KEYSWITCH-LED-MX-1U-LED; MX-1U-LED
,-1: KEYSWITCH-LED-MX-1U-LED; MX-1U-LED
-: KEYSWITCH-THTSMDLED-MX-1U-THTSMDLED; MX-1U-THTSMDLED
., .-1: KEYSWITCH-LED-MX-1U-LED; MX-1U-LED
/: KEYSWITCH-LED-MX-1U-LED; MX-1U-LED
/-1: KEYSWITCH-LED-MX-1U-LED; MX-1U-LED
=: KEYSWITCH-THTSMDLED-MX-1U-THTSMDLED; MX-1U-THTSMDLED
A: KEYSWITCH-THTSMDLED-MX-1U-THTSMDLED; MX-1U-THTSMDLED
ASHIFT: KEYSWITCH-THTSMDLED-MX-1U-THTSMDLED; MX-1U-THTSMDLED
B: KEYSWITCH-LED-MX-1U-LED; MX-1U-LED
B-1: KEYSWITCH-LED-MX-1U-LED; MX-1U-LED
BLE: MDBT40-NO-EXTRAMDBT40-NO-EXTRA; MDBT40-NO-EXTRA
BS: KEYSWITCH-THTSMDLED-MX-2U-THTSMDLED-FLIPPED; MX-2U-THTSMDLED-FLIPPED
BS-R: KEYSWITCH-THTSMDLED-MX-1U-THTSMDLED; MX-1U-THTSMDLED
C: KEYSWITCH-LED-MX-1U-LED; MX-1U-LED
C1, C2, C11, C13, C15, C16, C43, C44, C45: 10uF; C0603
C1_RST, C4, C5, C14, C19, C20, C21, C22, C23, C24, C25, C26, C27, C28, C29, C30, C31, C32, C33, C34, C35, C36, C37, C38, C39, C40, C41, C42: 100nF; C0603
C3, C6, C7, C10, C12: 1uF; C0603
C8, C9: 12pF; C0603
C-1: KEYSWITCH-LED-MX-1U-LED; MX-1U-LED
CAPS-STEPPED: KEYSWITCH-THTSMDLED-MX-1U-THTSMDLED; MX-1U-THTSMDLED
CAPS-TRAD: KEYSWITCH-THTSMDLED-MX-1U-THTSMDLED; MX-1U-THTSMDLED
D: KEYSWITCH-THTSMDLED-MX-1U-THTSMDLED; MX-1U-THTSMDLED
D1, D15, D16, D17, D18, D19, D20, D21, D22, D23, D24, D25, D26, D27, D28, D29, D30, D31, D32, D33, D34, D35, D36, D37, D38, D39, D40, D41, D42, D57, D58, D59, D60, D61, D62, D63, D64, D65, D66, D67, D68, D69, D70, D84, D85, D86, D87, D88, D89, D90, D91, D92, D93, D94, D95, D96, D111, D113, D115, D117, D119, D121, D123, D125, D127, D130: DIODE-SOD323-R; SOD323-R
D3, D4: MBR0520LT1G; SOD-123
D143: PMEG2005CT; SOT23
DFU: SJ
DOWN: KEYSWITCH-THTSMDLED-MX-1U-THTSMDLED; MX-1U-THTSMDLED
E: KEYSWITCH-THTSMDLED-MX-1U-THTSMDLED; MX-1U-THTSMDLED
ENTER-2U: KEYSWITCH-THTSMDLED-MX-2U-THTSMDLED-FLIPPED; MX-2U-THTSMDLED-FLIPPED
ESC: KEYSWITCH-THTSMDLED-MX-1U-THTSMDLED; MX-1U-THTSMDLED
F: KEYSWITCH-THTSMDLED-MX-1U-THTSMDLED; MX-1U-THTSMDLED
F1: MF-MSMF075-2; CAPC1210X112N
F.RST: SJ
G: KEYSWITCH-THTSMDLED-MX-1U-THTSMDLED; MX-1U-THTSMDLED
H: KEYSWITCH-THTSMDLED-MX-1U-THTSMDLED; MX-1U-THTSMDLED
I: KEYSWITCH-THTSMDLED-MX-1U-THTSMDLED; MX-1U-THTSMDLED
J: KEYSWITCH-THTSMDLED-MX-1U-THTSMDLED; MX-1U-THTSMDLED
J1: S2B-PH-K-S(LF)(SN); JST_S2B-PH-K-S(LF)(SN)
J2: SWD-2-WIRE; HEADER-2X1-2.54
K: KEYSWITCH-THTSMDLED-MX-1U-THTSMDLED; MX-1U-THTSMDLED
L: KEYSWITCH-THTSMDLED-MX-1U-THTSMDLED; MX-1U-THTSMDLED
L2: 120Ω @ 100MHz; 0402
L3: 1uH; INDC2009X120
LCMD: KEYSWITCH-THTSMDLED-MX-1U-THTSMDLED; MX-1U-THTSMDLED
LCTRL, LCTRL1: KEYSWITCH-PLAIN-MX-1U; MX-1U
LCTRL-LSMD1: LED-2-PLACEMENT-SMD; SMD-LED-UNIVERSAL-2-PLACEMENTS
LCTRL-LTHT1: LED-2-PLACEMENT-THT; LED-THT-2PLACEMENT
LED1, LED2, LED3, LED4, LED5, LED6, LED7, LED8, LED9, LED10: LED-4-PLACEMENT-SMD; SMD-LED-UNIVERSAL-DUAL
LEFT: KEYSWITCH-THTSMDLED-MX-1U-THTSMDLED; MX-1U-THTSMDLED
LOPT, LOPT1: KEYSWITCH-PLAIN-MX-1U; MX-1U
LOPT-LSMD1: LED-2-PLACEMENT-SMD; SMD-LED-UNIVERSAL-2-PLACEMENTS
LOPT-LTHT1: LED-2-PLACEMENT-THT; LED-THT-2PLACEMENT
LSHIFT-1U: KEYSWITCH-PLAIN-MX-2U-FLIPPED; MX-2U-FLIPPED
LSHIFT-LSMD: LED-2-PLACEMENT-SMD; SMD-LED-UNIVERSAL-2-PLACEMENTS
LSHIFT-LTHT: LED-2-PLACEMENT-THT; LED-THT-2PLACEMENT
LSHIFT-TRAD: KEYSWITCH-PLAIN-MX-2U-FLIPPED; MX-2U-FLIPPED
M: KEYSWITCH-LED-MX-1U-LED; MX-1U-LED
M-1: KEYSWITCH-LED-MX-1U-LED; MX-1U-LED
N: KEYSWITCH-LED-MX-1U-LED; MX-1U-LED
N-1: KEYSWITCH-LED-MX-1U-LED; MX-1U-LED
O: KEYSWITCH-THTSMDLED-MX-1U-THTSMDLED; MX-1U-THTSMDLED
P: KEYSWITCH-THTSMDLED-MX-1U-THTSMDLED; MX-1U-THTSMDLED
Q: KEYSWITCH-THTSMDLED-MX-1U-THTSMDLED; MX-1U-THTSMDLED
Q1: FDN337N; SSOT-3
Q2: FS8205A; SOP65P640X120-8N
R: KEYSWITCH-THTSMDLED-MX-1U-THTSMDLED; MX-1U-THTSMDLED
R1, R2: 5.1K; R0402
R1_RST, R3, R75, R77, R79, R80, R87: 10K; R0402
R4, R74, R88, R89: 1K; R0402
R5, R6: 22; R0402
R7, R8, R9, R10, R11, R12, R13, R14, R15, R16, R17, R18, R19, R20, R21, R22, R23, R24, R25, R26, R27, R28, R29, R30, R31, R32, R33, R34, R35, R36, R37, R38, R39, R40, R41, R42, R43, R44, R45, R46, R47, R48, R49, R50, R51, R52, R53, R54, R55, R56, R57, R58, R59, R60, R61, R62, R63, R64, R65, R66, R67, R68, R69, R70, R71, R73, R81, R82, R83, R85: 300; R0603
R72: 7.2K; R0402
R78: 270K; R0402
R86, R90: 100K; R0402
RCMD-1U: KEYSWITCH-PLAIN-MX-1U; MX-1U
RCMD-LSMD: LED-2-PLACEMENT-SMD; SMD-LED-UNIVERSAL-2-PLACEMENTS
RCMD-LTHT: LED-2-PLACEMENT-THT; LED-THT-2PLACEMENT
RCMD-TRAD: KEYSWITCH-PLAIN-MX-1U; MX-1U
RIGHT: KEYSWITCH-PLAIN-MX-1U; MX-1U
RIGHT-LSMD: LED-2-PLACEMENT-SMD; SMD-LED-UNIVERSAL-2-PLACEMENTS
RIGHT-LTHT: LED-2-PLACEMENT-THT; LED-THT-2PLACEMENT
RMOD1-TRAD: KEYSWITCH-THTSMDLED-MX-1U-THTSMDLED; MX-1U-THTSMDLED
RMOD2-TRAD: KEYSWITCH-PLAIN-MX-1U; MX-1U
ROPT-1U: KEYSWITCH-THTSMDLED-MX-1U-THTSMDLED; MX-1U-THTSMDLED
ROPT-TRAD: KEYSWITCH-THTSMDLED-MX-1U-THTSMDLED; MX-1U-THTSMDLED
RSHIFT-1U: KEYSWITCH-THTSMDLED-MX-1U-THTSMDLED; MX-1U-THTSMDLED
RSHIFT-TRAD: KEYSWITCH-PLAIN-MX-1U; MX-1U
RST: SJ
S: KEYSWITCH-THTSMDLED-MX-1U-THTSMDLED; MX-1U-THTSMDLED
S2: SSSS213000
SEMICOL: KEYSWITCH-THTSMDLED-MX-1U-THTSMDLED; MX-1U-THTSMDLED
SPACE: KEYSWITCH-THTSMDLED-MX-6.25U-THTSMDLED; MX-6.25U-THTSMDLED
T: KEYSWITCH-THTSMDLED-MX-1U-THTSMDLED; MX-1U-THTSMDLED
TAB: KEYSWITCH-THTSMDLED-MX-1U-THTSMDLED; MX-1U-THTSMDLED
TS_SH: KEYSWITCH-THTSMDLED-MX-1U-THTSMDLED; MX-1U-THTSMDLED
U: KEYSWITCH-THTSMDLED-MX-1U-THTSMDLED; MX-1U-THTSMDLED
U1: MIC5205-3.3YM5TR; SOT95P280X130-5N
U2: SN74LVC2G34DBVR; SOT95P280X145-6N
U3: AT90USB646; QFN50P900X900X100-65N
U4: USBLC6-2P6; SOT50P160X60-6N
U5: FS312F-G
U6: MCP73871-2AAI/ML; QFN50P400X400X100-21N
U7: TPS61252DSGT; SON50P200X200X80-9N
U$1: BSS138; SOT-23
U$5, U$6, U$7, U$8, U$9, U$10, U$11, U$12, U$13, U$14, U$15, U$16, U$17, U$18, U$19, U$20, U$21, U$22, U$23, U$24, U$25, U$26, U$27, U$28: SK6805
U$29, U$30, U$31, U$32, U$33, U$34, U$35, U$36, U$37, U$38, U$39, U$40, U$41, U$42, U$43, U$44, U$45, U$46, U$47, U$48, U$49, U$50, U$51, U$52, U$53, U$54, U$55, U$56, U$57, U$58, U$59, U$60, U$61, U$62, U$63, U$64, U$65, U$66, U$67, U$68, U$69, U$70, U$71, U$72, U$73, U$74, U$75, U$76, U$77, U$78, U$79, U$80, U$81, U$82, U$83, U$84, U$85, U$86, U$87, U$88, U$89, U$90, U$91, U$92: LED-0805; LED0805
UP: KEYSWITCH-PLAIN-MX-1U; MX-1U
UP-LSMD: LED-2-PLACEMENT-SMD; SMD-LED-UNIVERSAL-2-PLACEMENTS
UP-LTHT: LED-2-PLACEMENT-THT; LED-THT-2PLACEMENT
USB-C: USB-C; TYPE-C-31-M-12
V: KEYSWITCH-LED-MX-1U-LED; MX-1U-LED
V-1: KEYSWITCH-LED-MX-1U-LED; MX-1U-LED
W: KEYSWITCH-THTSMDLED-MX-1U-THTSMDLED; MX-1U-THTSMDLED
X: KEYSWITCH-LED-MX-1U-LED; MX-1U-LED
X-1: KEYSWITCH-LED-MX-1U-LED; MX-1U-LED
Y: KEYSWITCH-THTSMDLED-MX-1U-THTSMDLED; MX-1U-THTSMDLED
Y1: 8MHz; CRYSTAL-3.2X2.5
Z: KEYSWITCH-LED-MX-1U-LED; MX-1U-LED
Z-1: KEYSWITCH-LED-MX-1U-LED; MX-1U-LED
[: KEYSWITCH-THTSMDLED-MX-1U-THTSMDLED; MX-1U-THTSMDLED
]: KEYSWITCH-THTSMDLED-MX-1U-THTSMDLED; MX-1U-THTSMDLED
|: KEYSWITCH-THTSMDLED-MX-1U-THTSMDLED; MX-1U-THTSMDLED
~: KEYSWITCH-THTSMDLED-MX-1U-THTSMDLED; MX-1U-THTSMDLED

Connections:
ADCV: R72.2, R75.1, U3.55 (PF6_(ADC6/TDO))
AREF: C5.2, U3.62 (AREF)
BATT+: R72.1, R73.2, R82.2, R83.2, S2.P3 (3), U6.14 (VBAT), U6.15 (VBAT), U6.16 (VBAT_SENSE)
BATT-: C14.1, J1.1, Q2.6 (S2), Q2.7 (S2), U5.6 (GND)
BATTSWITCH: J1.2, S2.P2 (2)
BL: R71.1, U3.16 ((PCINT6/OC.1B)_PB6)
COL1: CAPS-STEPPED.MX2 (P1), CAPS-TRAD.MX2 (P1), LCTRL.MX2 (P1), LCTRL1.MX2 (P1), LSHIFT-1U.MX2 (P1), LSHIFT-TRAD.MX2 (P1), TAB.MX2 (P1), U3.51 (PA0_(AD0)), ~.MX2 (P1)
COL2: 1.MX2 (P1), A.MX2 (P1), LOPT.MX2 (P1), LOPT1.MX2 (P1), Q.MX2 (P1), U3.50 (PA1_(AD1)), Z.MX2 (P1), Z-1.MX2 (P1)
COL3: 2.MX2 (P1), LCMD.MX2 (P1), S.MX2 (P1), U3.49 (PA2_(AD2)), W.MX2 (P1), X.MX2 (P1), X-1.MX2 (P1)
COL4: 3.MX2 (P1), C.MX2 (P1), C-1.MX2 (P1), D.MX2 (P1), E.MX2 (P1), U3.48 (PA3_(AD3))
COL5: 4.MX2 (P1), F.MX2 (P1), R.MX2 (P1), U3.47 (PA4_(AD4)), V.MX2 (P1), V-1.MX2 (P1)
COL6: 5.MX2 (P1), B.MX2 (P1), B-1.MX2 (P1), G.MX2 (P1), SPACE.MX2 (P1), T.MX2 (P1), U3.46 (PA5_(AD5))
COL7: 6.MX2 (P1), H.MX2 (P1), N.MX2 (P1), N-1.MX2 (P1), U3.44 (PA7_(AD7)), Y.MX2 (P1)
COL8: 7.MX2 (P1), J.MX2 (P1), M.MX2 (P1), M-1.MX2 (P1), U.MX2 (P1), U3.45 (PA6_(AD6))
COL9: 8.MX2 (P1), ,.MX2 (P1), ,-1.MX2 (P1), I.MX2 (P1), K.MX2 (P1), U3.38 (PC3_(A11/T.3))
COL10: 9.MX2 (P1), ..MX2 (P1), .-1.MX2 (P1), L.MX2 (P1), O.MX2 (P1), RCMD-1U.MX2 (P1), RCMD-TRAD.MX2 (P1), U3.37 (PC2_(A10))
COL11: 0.MX2 (P1), /.MX2 (P1), /-1.MX2 (P1), P.MX2 (P1), ROPT-1U.MX2 (P1), ROPT-TRAD.MX2 (P1), SEMICOL.MX2 (P1), U3.36 (PC1_(A9))
COL12: '.MX2 (P1), -.MX2 (P1), ASHIFT.MX2 (P1), LEFT.MX2 (P1), RMOD1-TRAD.MX2 (P1), RSHIFT-1U.MX2 (P1), TS_SH.MX2 (P1), U3.35 (PC0_(A8)), [.MX2 (P1)
COL13: =.MX2 (P1), DOWN.MX2 (P1), ENTER-2U.MX2 (P1), RSHIFT-TRAD.MX2 (P1), U3.34 (PE1_(~RD)), UP.MX2 (P1), ].MX2 (P1)
COL14: 1U-BS.MX2 (P1), BS.MX2 (P1), BS-R.MX2 (P1), ESC.MX2 (P1), RIGHT.MX2 (P1), RMOD2-TRAD.MX2 (P1), U3.33 (PE0_(~WR)), |.MX2 (P1)
CS_3.3V: BLE.7 (P0.24), D130.A, R3.1
CS_5V: D130.C, U3.14 ((PCINT4/OC.2A)_PB4)
GND: BLE.1 (GND), BLE.2 (GND), BLE.13 (GND), BLE.16 (P0.30), BLE.25 (GND), BLE.42 (GND), C1.1, C1_RST.1, C2.1, C3.1, C4.1, C5.1, C6.1, C7.1, C8.2, C9.2, C10.1, C11.1, C12.1, C13.1, C15.1, C16.1, C19.1, C20.1, C21.1, C22.1, C23.1, C24.1, C25.1, C26.1, C27.1, C28.1, C29.1, C30.1, C31.1, C32.1, C33.1, C34.1, C35.1, C36.1, C37.1, C38.1, C39.1, C40.1, C41.1, C42.1, C43.1, C44.1, C45.1, DFU.2, F.RST.2, Q1.2 (S), Q2.2 (S1), Q2.3 (S1), R1.1, R2.2, R4.1, R74.1, R75.2, R77.1, R86.1, R87.1, R88.1, R90.1, RST.1, U1.2 (GND), U2.2 (GND), U3.6 (UGND), U3.22 (GND), U3.53 (GND), U3.63 (GND), U3.65 (EPAD), U4.2 (GND), U6.3 (SEL), U6.10 (VSS), U6.11 (VSS), U6.21 (EP), U7.1 (GND), U7.5 (PG), U7.9 (EP), U$5.GND, U$6.GND, U$7.GND, U$8.GND, U$9.GND, U$10.GND, U$11.GND, U$12.GND, U$13.GND, U$14.GND, U$15.GND, U$16.GND, U$17.GND, U$18.GND, U$19.GND, U$20.GND, U$21.GND, U$22.GND, U$23.GND, U$24.GND, U$25.GND, U$26.GND, U$27.GND, U$28.GND, USB-C.A1 (GND), USB-C.B1 (GND), USB-C.SHIELD@1 (SHIELD), USB-C.SHIELD@2 (SHIELD)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
IRQ: BLE.8 (P0.25), U3.18 ((INT4/TOSC1)_PE4)
LED_OUT: 0.LED-, 0.SMDLED- (LED-), 1.LED-, 1.SMDLED- (LED-), 1U-BS.LED-, 1U-BS.SMDLED- (LED-), 2.LED-, 2.SMDLED- (LED-), 3.LED-, 3.SMDLED- (LED-), 4.LED-, 4.SMDLED- (LED-), 5.LED-, 5.SMDLED- (LED-), 6.LED-, 6.SMDLED- (LED-), 7.LED-, 7.SMDLED- (LED-), 8.LED-, 8.SMDLED- (LED-), 9.LED-, 9.SMDLED- (LED-), '.LED-, '.SMDLED- (LED-), ,.LED-, ,-1.LED-, -.LED-, -.SMDLED- (LED-), ..LED-, .-1.LED-, /.LED-, /-1.LED-, =.LED-, =.SMDLED- (LED-), A.LED-, A.SMDLED- (LED-), ASHIFT.LED-, ASHIFT.SMDLED- (LED-), B.LED-, B-1.LED-, BS.LED-, BS.SMDLED- (LED-), BS-R.LED-, BS-R.SMDLED- (LED-), C.LED-, C-1.LED-, CAPS-STEPPED.LED-, CAPS-STEPPED.SMDLED- (LED-), CAPS-TRAD.LED-, CAPS-TRAD.SMDLED- (LED-), D.LED-, D.SMDLED- (LED-), DOWN.LED-, DOWN.SMDLED- (LED-), E.LED-, E.SMDLED- (LED-), ENTER-2U.LED-, ENTER-2U.SMDLED- (LED-), ESC.LED-, ESC.SMDLED- (LED-), F.LED-, F.SMDLED- (LED-), G.LED-, G.SMDLED- (LED-), H.LED-, H.SMDLED- (LED-), I.LED-, I.SMDLED- (LED-), J.LED-, J.SMDLED- (LED-), K.LED-, K.SMDLED- (LED-), L.LED-, L.SMDLED- (LED-), LCMD.LED-, LCMD.SMDLED- (LED-), LCTRL-LSMD1.MINUS1 (MINUS), LCTRL-LSMD1.MINUS2 (MINUS), LCTRL-LTHT1.1 (MINUS), LED1.MINUS1 (MINUS), LED1.MINUS2 (MINUS), LED2.MINUS1 (MINUS), LED2.MINUS2 (MINUS), LED3.MINUS1 (MINUS), LED3.MINUS2 (MINUS), LED4.MINUS1 (MINUS), LED4.MINUS2 (MINUS), LED5.MINUS1 (MINUS), LED5.MINUS2 (MINUS), LED6.MINUS1 (MINUS), LED6.MINUS2 (MINUS), LED7.MINUS1 (MINUS), LED7.MINUS2 (MINUS), LED8.MINUS1 (MINUS), LED8.MINUS2 (MINUS), LED9.MINUS1 (MINUS), LED9.MINUS2 (MINUS), LED10.MINUS1 (MINUS), LED10.MINUS2 (MINUS), LEFT.LED-, LEFT.SMDLED- (LED-), LOPT-LSMD1.MINUS1 (MINUS), LOPT-LSMD1.MINUS2 (MINUS), LOPT-LTHT1.1 (MINUS), LSHIFT-LSMD.MINUS1 (MINUS), LSHIFT-LSMD.MINUS2 (MINUS), LSHIFT-LTHT.1 (MINUS), M.LED-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
LSHIFT-LED-ITC1: LSHIFT-LSMD.PLUS, LSHIFT-LTHT.2 (PLUS), LSHIFT-LTHT.3 (PLUS), R70.1
MISO_3.3V: BLE.5 (P0.22), U3.13 ((PDO/PCINT3/MISO)_PB3)
MOSI_3.3V: BLE.6 (P0.23), U2.4 (2Y)
MOSI_5V: U2.3 (2A), U3.12 ((PDI/PCINT2/MOSI)_PB2)
unnamed: D15.A, ~.MX1 (P0)
unnamed: 1.MX1 (P0), D16.A
unnamed: 3.MX1 (P0), D18.A
unnamed: D30.A, Q.MX1 (P0)
unnamed: D29.A, TAB.MX1 (P0)
unnamed: 4.MX1 (P0), D19.A
unnamed: D31.A, W.MX1 (P0)
unnamed: 2.MX1 (P0), D17.A
unnamed: 5.MX1 (P0), D20.A
unnamed: D32.A, E.MX1 (P0)
unnamed: 6.MX1 (P0), D21.A
unnamed: D33.A, R.MX1 (P0)
unnamed: 7.MX1 (P0), D22.A
unnamed: R1.2, USB-C.A5 (CC1)
unnamed: D34.A, T.MX1 (P0)
unnamed: 8.MX1 (P0), D23.A
unnamed: D35.A, Y.MX1 (P0)
unnamed: 9.MX1 (P0), D24.A
unnamed: D36.A, U.MX1 (P0)
unnamed: 0.MX1 (P0), D25.A
unnamed: D37.A, I.MX1 (P0)
unnamed: -.MX1 (P0), D26.A
unnamed: D38.A, O.MX1 (P0)
unnamed: =.MX1 (P0), D27.A
unnamed: D39.A, P.MX1 (P0)
unnamed: 1U-BS.MX1 (P0), BS.MX1 (P0), D28.A
unnamed: D3.A, F1.2 (OUT)
unnamed: D40.A, [.MX1 (P0)
unnamed: D41.A, ].MX1 (P0)
unnamed: D42.A, |.MX1 (P0)
unnamed: C1.2, D3.C, L2.1
unnamed: A.MX1 (P0), D58.A
unnamed: CAPS-STEPPED.MX1 (P0), CAPS-TRAD.MX1 (P0), D57.A
unnamed: D59.A, S.MX1 (P0)
unnamed: D.MX1 (P0), D60.A
unnamed: D61.A, F.MX1 (P0)
unnamed: D62.A, G.MX1 (P0)
unnamed: D63.A, H.MX1 (P0)
unnamed: D64.A, J.MX1 (P0)
unnamed: D65.A, K.MX1 (P0)
unnamed: D66.A, L.MX1 (P0)
unnamed: D67.A, SEMICOL.MX1 (P0)
unnamed: '.MX1 (P0), D68.A
unnamed: D69.A, ENTER-2U.MX1 (P0)
unnamed: D84.A, Z.MX1 (P0), Z-1.MX1 (P0)
unnamed: LED1.PLUS1 (PLUS), LED1.PLUS2 (PLUS), R12.1, Z.LED+, Z-1.LED+
unnamed: R7.1, ~.LED+, ~.SMDLED+ (LED+)
unnamed: D85.A, X.MX1 (P0), X-1.MX1 (P0)
unnamed: C.MX1 (P0), C-1.MX1 (P0), D86.A
unnamed: D87.A, V.MX1 (P0), V-1.MX1 (P0)
unnamed: B.MX1 (P0), B-1.MX1 (P0), D88.A
unnamed: D89.A, N.MX1 (P0), N-1.MX1 (P0)
unnamed: D90.A, M.MX1 (P0), M-1.MX1 (P0)
unnamed: ,.MX1 (P0), ,-1.MX1 (P0), D91.A
unnamed: D95.A, RSHIFT-TRAD.MX1 (P0), UP.MX1 (P0)
unnamed: ..MX1 (P0), .-1.MX1 (P0), D92.A
unnamed: /.MX1 (P0), /-1.MX1 (P0), D93.A
unnamed: BLE.24 (P0.07), DFU.1
unnamed: ASHIFT.MX1 (P0), D94.A, RSHIFT-1U.MX1 (P0), TS_SH.MX1 (P0)
unnamed: 2.LED+, 2.SMDLED+ (LED+), R16.1
unnamed: D96.A, ESC.MX1 (P0)
unnamed: R8.1, TAB.LED+, TAB.SMDLED+ (LED+)
unnamed: D70.A, LSHIFT-1U.MX1 (P0), LSHIFT-TRAD.MX1 (P0)
unnamed: R2.1, USB-C.B5 (CC2)
unnamed: Q1.1 (G), R71.2, R77.2
unnamed: LED2.PLUS1 (PLUS), LED2.PLUS2 (PLUS), R19.1, X.LED+, X-1.LED+
unnamed: C14.2, R73.1, R82.1, R83.1, U5.5 (VCC)
unnamed: LED4.PLUS1 (PLUS), LED4.PLUS2 (PLUS), R28.1, V.LED+, V-1.LED+
unnamed: 8.LED+, 8.SMDLED+ (LED+), R42.1
unnamed: 5.LED+, 5.SMDLED+ (LED+), R33.1
unnamed: D111.A, LCTRL.MX1 (P0), LCTRL1.MX1 (P0)
unnamed: LOPT-LSMD1.PLUS, LOPT-LTHT1.2 (PLUS), LOPT-LTHT1.3 (PLUS), R11.1
unnamed: R74.2, U5.2 (CS)
unnamed: R78.1, R86.2, U7.3 (FB)
unnamed: LCTRL-LSMD1.PLUS, LCTRL-LTHT1.2 (PLUS), LCTRL-LTHT1.3 (PLUS), R10.1
unnamed: B.LED+, B-1.LED+, LED5.PLUS1 (PLUS), LED5.PLUS2 (PLUS), R30.1
unnamed: LED6.PLUS1 (PLUS), LED6.PLUS2 (PLUS), N.LED+, N-1.LED+, R37.1
unnamed: LED7.PLUS1 (PLUS), LED7.PLUS2 (PLUS), M.LED+, M-1.LED+, R38.1
unnamed: ,.LED+, ,-1.LED+, LED8.PLUS1 (PLUS), LED8.PLUS2 (PLUS), R45.1
unnamed: ..LED+, .-1.LED+, LED9.PLUS1 (PLUS), LED9.PLUS2 (PLUS), R47.1
unnamed: /.LED+, /-1.LED+, LED10.PLUS1 (PLUS), LED10.PLUS2 (PLUS), R54.1
unnamed: CAPS-STEPPED.LED+, CAPS-STEPPED.SMDLED+ (LED+), CAPS-TRAD.LED+, CAPS-TRAD.SMDLED+ (LED+), R9.1
unnamed: D113.A, LOPT.MX1 (P0), LOPT1.MX1 (P0)
unnamed: D115.A, LCMD.MX1 (P0)
unnamed: A.LED+, A.SMDLED+ (LED+), R13.1
unnamed: D117.A, SPACE.MX1 (P0)
unnamed: D119.A, RCMD-1U.MX1 (P0), RCMD-TRAD.MX1 (P0)
unnamed: Q.LED+, Q.SMDLED+ (LED+), R14.1
unnamed: D121.A, ROPT-1U.MX1 (P0), ROPT-TRAD.MX1 (P0)
unnamed: R4.2, U3.43 (PE2_(ALE/HWB))
unnamed: D123.A, LEFT.MX1 (P0), RMOD1-TRAD.MX1 (P0)
unnamed: 1.LED+, 1.SMDLED+ (LED+), R15.1
unnamed: D125.A, DOWN.MX1 (P0)
unnamed: D127.A, RIGHT.MX1 (P0), RMOD2-TRAD.MX1 (P0)
unnamed: LCMD.LED+, LCMD.SMDLED+ (LED+), R20.1
unnamed: R18.1, S.LED+, S.SMDLED+ (LED+)
unnamed: R17.1, W.LED+, W.SMDLED+ (LED+)
unnamed: 3.LED+, 3.SMDLED+ (LED+), R24.1
unnamed: E.LED+, E.SMDLED+ (LED+), R23.1
unnamed: D.LED+, D.SMDLED+ (LED+), R22.1
unnamed: C.LED+, C-1.LED+, LED3.PLUS1 (PLUS), LED3.PLUS2 (PLUS), R21.1
unnamed: F.LED+, F.SMDLED+ (LED+), R27.1
unnamed: R.LED+, R.SMDLED+ (LED+), R26.1
unnamed: 4.LED+, 4.SMDLED+ (LED+), R25.1
unnamed: R32.1, T.LED+, T.SMDLED+ (LED+)
unnamed: G.LED+, G.SMDLED+ (LED+), R31.1
unnamed: R29.1, SPACE.LED+, SPACE.SMDLED+ (LED+)
unnamed: H.LED+, H.SMDLED+ (LED+), R36.1
unnamed: R35.1, Y.LED+, Y.SMDLED+ (LED+)
unnamed: 6.LED+, 6.SMDLED+ (LED+), R34.1
unnamed: 7.LED+, 7.SMDLED+ (LED+), R41.1
unnamed: R40.1, U.LED+, U.SMDLED+ (LED+)
unnamed: J.LED+, J.SMDLED+ (LED+), R39.1
unnamed: K.LED+, K.SMDLED+ (LED+), R44.1
unnamed: I.LED+, I.SMDLED+ (LED+), R43.1
unnamed: 9.LED+, 9.SMDLED+ (LED+), R50.1
unnamed: O.LED+, O.SMDLED+ (LED+), R49.1
unnamed: L.LED+, L.SMDLED+ (LED+), R48.1
unnamed: R55.1, ROPT-1U.LED+, ROPT-1U.SMDLED+ (LED+), ROPT-TRAD.LED+, ROPT-TRAD.SMDLED+ (LED+)
unnamed: R53.1, SEMICOL.LED+, SEMICOL.SMDLED+ (LED+)
unnamed: P.LED+, P.SMDLED+ (LED+), R52.1
unnamed: 0.LED+, 0.SMDLED+ (LED+), R51.1
unnamed: -.LED+, -.SMDLED+ (LED+), R60.1
unnamed: R59.1, [.LED+, [.SMDLED+ (LED+)
unnamed: '.LED+, '.SMDLED+ (LED+), R58.1
unnamed: ASHIFT.LED+, ASHIFT.SMDLED+ (LED+), R57.1, RSHIFT-1U.LED+, RSHIFT-1U.SMDLED+ (LED+)
unnamed: LEFT.LED+, LEFT.SMDLED+ (LED+), R56.1, RMOD1-TRAD.LED+, RMOD1-TRAD.SMDLED+ (LED+)
unnamed: DOWN.LED+, DOWN.SMDLED+ (LED+), R65.1
unnamed: ENTER-2U.LED+, ENTER-2U.SMDLED+ (LED+), R63.1
unnamed: R62.1, ].LED+, ].SMDLED+ (LED+)
unnamed: =.LED+, =.SMDLED+ (LED+), R61.1
unnamed: 1U-BS.LED+, 1U-BS.SMDLED+ (LED+), BS.LED+, BS.SMDLED+ (LED+), R69.1
unnamed: R68.1, |.LED+, |.SMDLED+ (LED+)
unnamed: ESC.LED+, ESC.SMDLED+ (LED+), R67.1
unnamed: L3.2, U7.7 (SW)
unnamed: BS-R.MX1 (P0), D1.A
unnamed: R88.2, R89.1
unnamed: R87.2, U6.5 (THERM)
unnamed: R89.2, U6.13 (PROG1)
unnamed: R90.2, U6.12 (PROG3)
unnamed: BLE.34 (P0.16), F.RST.1
unnamed: C10.2, D143.3 (K1K2), U1.1 (IN), U1.3 (EN)
unnamed: BS-R.LED+, BS-R.SMDLED+ (LED+), R81.1
unnamed: U$5.DOUT, U$6.DIN
unnamed: U$6.DOUT, U$7.DIN
unnamed: U$7.DOUT, U$8.DIN
unnamed: U$8.DOUT, U$9.DIN
unnamed: U$9.DOUT, U$10.DIN
unnamed: U$10.DOUT, U$11.DIN
unnamed: U$11.DOUT, U$12.DIN
unnamed: U$13.DOUT, U$14.DIN
unnamed: U$21.DOUT, U$22.DIN
unnamed: U$22.DOUT, U$23.DIN
unnamed: U$14.DOUT, U$15.DIN
unnamed: U$15.DOUT, U$16.DIN
unnamed: U$23.DOUT, U$24.DIN
unnamed: U$24.DOUT, U$25.DIN
unnamed: U$16.DOUT, U$17.DIN
unnamed: U$17.DOUT, U$18.DIN
unnamed: U$18.DOUT, U$19.DIN
unnamed: U$25.DOUT, U$26.DIN
unnamed: U$26.DOUT, U$27.DIN
unnamed: U$19.DOUT, U$20.DIN
unnamed: U$27.DOUT, U$28.DIN
unnamed: R85.2, U$5.DIN
unnamed: U$12.DOUT, U$13.DIN
unnamed: U$20.DOUT, U$21.DIN
OC: Q2.4 (G1), U5.3 (OC)
OD: Q2.5 (G2), U5.1 (OD)
RCMD-LED-ITC1: R46.1, RCMD-LSMD.PLUS, RCMD-LTHT.2 (PLUS), RCMD-LTHT.3 (PLUS)
RIGHT-LED-ITC1: R66.1, RIGHT-LSMD.PLUS, RIGHT-LTHT.2 (PLUS), RIGHT-LTHT.3 (PLUS)
ROW1: D15.C, D16.C, D17.C, D18.C, D19.C, D20.C, D21.C, D22.C, D23.C, D24.C, D25.C, D26.C, D27.C, D28.C, U3.61 (PF0_(ADC0))
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

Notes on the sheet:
4.5
5.5
MCU Support
Per-Key LED Subsystem
Power Management Subsystem
Note that 12pF is for a crystal w/ Load Capacitance of 10pF. Part chosen for crystal is 10pF. Adjust if necessary. Cap = 2*CL - 2*C_[stray] where C_[stray] is assumed to be 2pF. Closest common value chosen
Datasheet for FS312F-G gives 100Ω for VCC Resist. Equiv. = 3x 300Ω in Parr.
USB Connector
MDBT40-256v3 BLE Subsystem
RGB Underglow Subsystem
Decoupling Caps
Crystal
Reset
Support Caps
USB Filtering and Protection
Battery Charging
DC-DC Boost Converter
Li-Ion Battery Protection
Battery Connector
Level Shifters
Voltage Regulation
Main MDBT40 Chip
Programming Pads
VBUS is passed through a 500mA fuse followed by a Schottky Diode This creates overcurrent and backflow protection High Frequency EMC is filtered by a ferrite bead and output is smoothed by decoupling capacitors
Battery Level
SMD LED Pick and Place Positions\
These LED's are not electrically connected and are only used to add positions for the Pick-and-Place Centroid file needed for assembly.

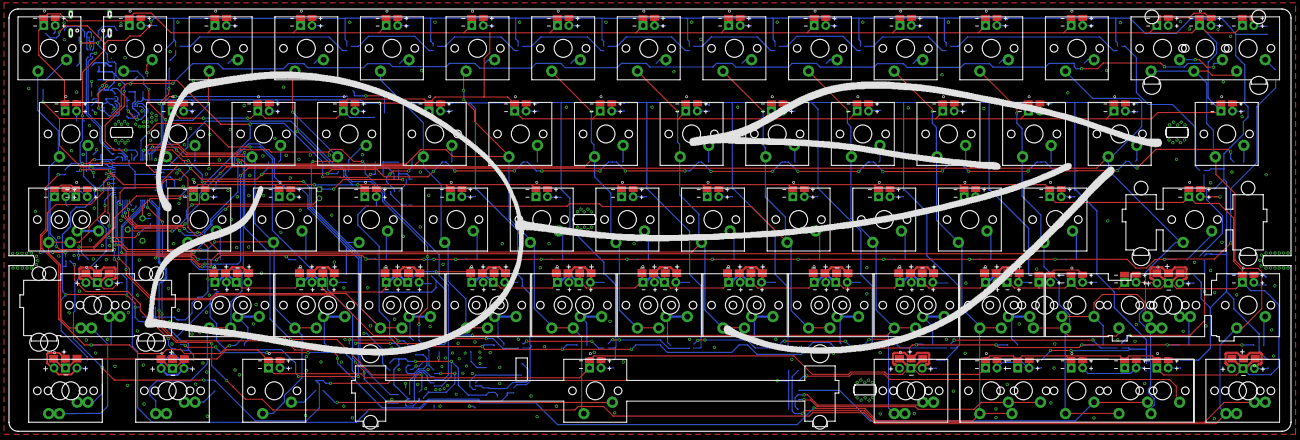
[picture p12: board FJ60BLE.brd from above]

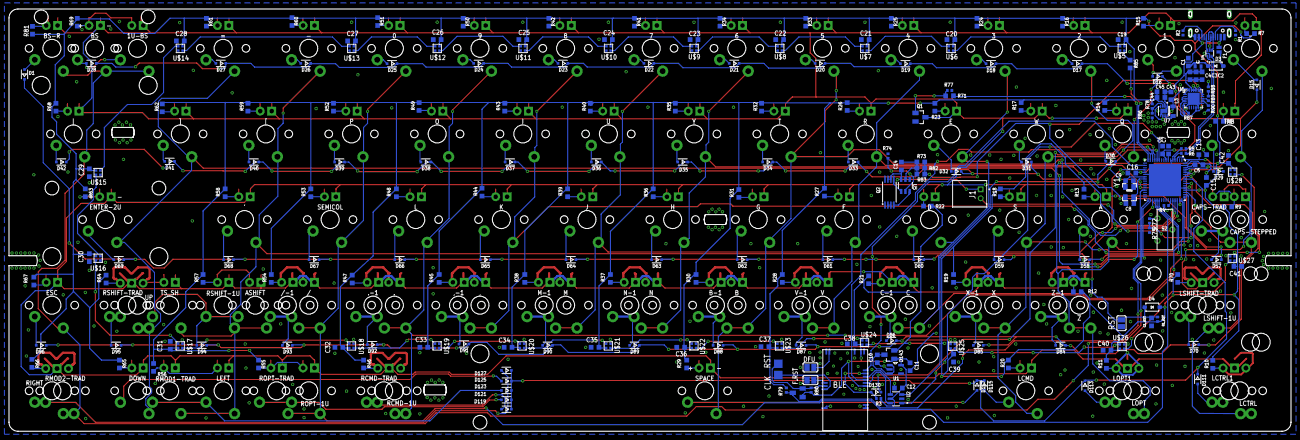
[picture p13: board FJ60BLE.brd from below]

Board: 2 copper layers, 285.2 x 94.0 mm, 424 parts (250 on the bottom side), 227 nets.

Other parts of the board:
U$3: FJLABSLOGO
U$4: FJ60BLXV1.0
U$93: WHITE_TULIP

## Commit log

2020-08-29 Screwed up readme format
2020-09-07 Added Sept. 4th Version as manufactured
    [FJ60BLE.brd, FJ60BLE.sch, GitHub BOM 9-4-2020.xlsx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]

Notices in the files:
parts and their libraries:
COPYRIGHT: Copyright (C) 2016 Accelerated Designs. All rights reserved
